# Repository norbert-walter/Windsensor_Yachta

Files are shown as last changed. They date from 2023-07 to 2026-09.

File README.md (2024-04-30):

## Windsensor Yachta

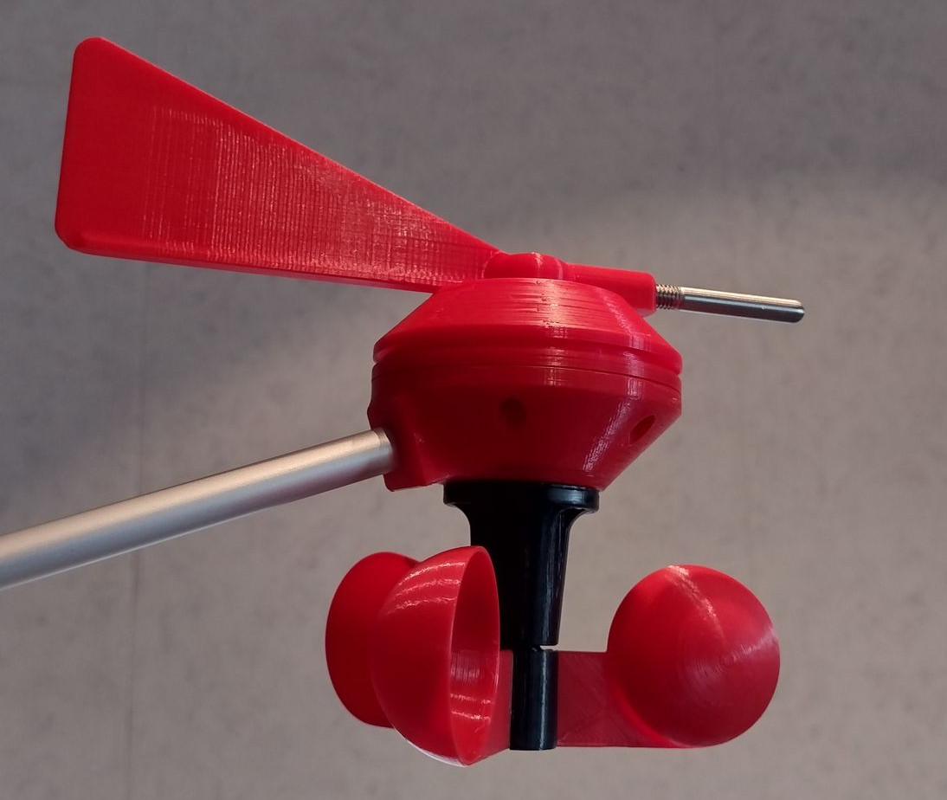
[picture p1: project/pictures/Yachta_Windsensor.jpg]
Windsnesor Yachta


Image: Wind Sensor Yachta

The initial idea for the Yachta wind sensor is based on a work by the user Yachta. He presented and published the wind sensor on [Thingiverse](https://www.thingiverse.com/thing:2261719). Udo took up the idea of Yachta and modified the mechanics a little. The arms of the cup wheel have been separated. This makes 3D printing easier to implement. The electronics were completely redesigned by him. The microcontroller was removed and replaced with an ESP8266. A DC/DC converter module was installed so that the wind sensor can also be operated at 12V. The circuit board was created with the Windows software Sprint Layout and converted into Gerber files. Now is a new BCP available from Norbert.

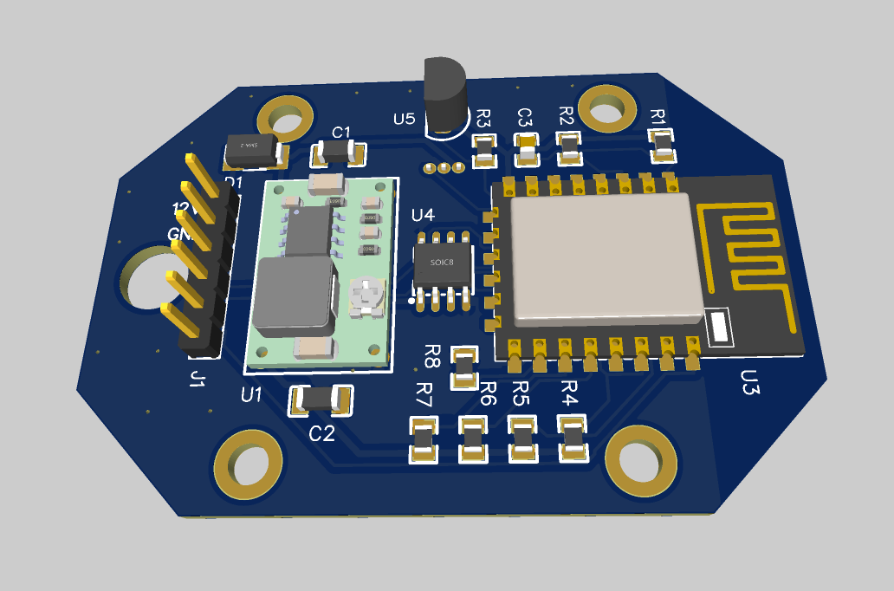
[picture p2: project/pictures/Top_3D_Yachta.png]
Windsnesor Yachta


Image: PCB board

The PCB project is listed on [Open Source Hardware Lab](https://oshwlab.com/) an can be edited with the webbased online [layout program EasyEDA](https://easyeda.com/norbert-walter/projects).

The board without components can be ordered from [Aisler](https://aisler.net/p/VTNPJWKQ) or direct in EasyEDA.

There are different firmware for the wind sensor. Both Udo and Julian ([Jukolein](https://github.com/jukolein/NMEA0183-Windsensor)) have created their own firmware versions with different functionality. Udo has also designed another wind sensor, which is a further development of the Yachta wind sensor. The functional principle and the electronics are identical. But you need a different board because the wind sensor is slimmer. Julian published the whole thing on [Github](https://github.com/jukolein/NMEA0183-Windsensor) and wrote his own firmware for the wind sensor, which can also be used for this wind sensor. 

The WiFi 1000 firmware is a firmware that can be used universally for various wind sensors and was originally developed by Norbert for the [WiFi 1000 wind sensor](https://gitlab.com/norbertwalter67/Windsensor_WiFi_1000). The current versions of the firmware can be found in the respective own repositories at Github and GitLab.

A lively exchange of experiences takes place in the German-speaking [sailing forum](https://www.segeln-forum.de/board194-boot-technik/board195-open-boat-projects-org/79131-windsensor-ii-iii/). You can also participate in English.

If you like to help or consider this project useful, please donate. Thanks for your support!

Donate (https://www.paypal.com/cgi-bin/webscr?cmd=_s-xclick&hosted_button_id=5QZJZBM252F2L)

## Technical characteristics

* Measuring wind speed and wind direction
* Robust mechanics
* Without special metal parts
* All parts can be found in the hardware store
* Easy 3D parts
* Weight app. 210g
* Weatherproof and UV stable
* No cabling for sensor signals
* Digital signal transmission with WiFi only
* 12V power supply utilizing top light power cable
* Using a ESP8266 for WiFi and data handling
* Update rate 1 samples per second
* No onboard instrument required
* Visualisation in OpenPlotter via laptop, mobile fone or tablett
* Web interface for operation
* No extra software required (display is the browser)
* Supporting  NMEA 0183 protocol
* Firmware update via Internet

## Create your own code

You have the option of creating your own code using the online [software development environment Gitpod](https://gitpod.io/#https://github.com/norbert-walter/Windsensor_Yachta). Follow this link and a finished development environment similar to PlatformIO will be created that runs in your browser with all code components. To compile the software, enter ***bash run*** in the terminal. In the workspace you will find the compiled binary code under ***.pio/build/d1_mini/firmware.bin***. With a right click you can download the binary file.

## Device flash process

With the [Web Flash Tool](https://norbert-walter.github.io/Windsensor_Yachta/flash_tool/esp_flash_tool.html) you can very easily flash the device with the firmware from the web browser. You need a Chrome or Edge browser and a USB connection cable. If the device is connected to the USB port of the computer, the serial connection can be selected and the flash process can then be started.

## Firmware characteristics

**Wind Sensor Yachta Firmware**
* Web configuration and graphical visualisation
* Webserver port 80
* TCP port 6666
* TCP NMEA0183 telegram MWV, VWR, VPW, INF
* JSON http://192.168.4.1/json
* Firmware update via Internet
* Android App

## How can I use it?

I use the windsensor in combination with [OpenPlotter](http://www.sailoog.com/openplotter) on a Raspberry Pi 3B. OpenPlotter serves as access point for WiFi devices. The windsensor connects to OpenPlotter via WiFi and transmits the NMEA0183 data telegrams every second. The windsensor sends NMEA0183 telegrams. Check here [link](http://www.nmea.de/nmea0183datensaetze.html) for more information. 

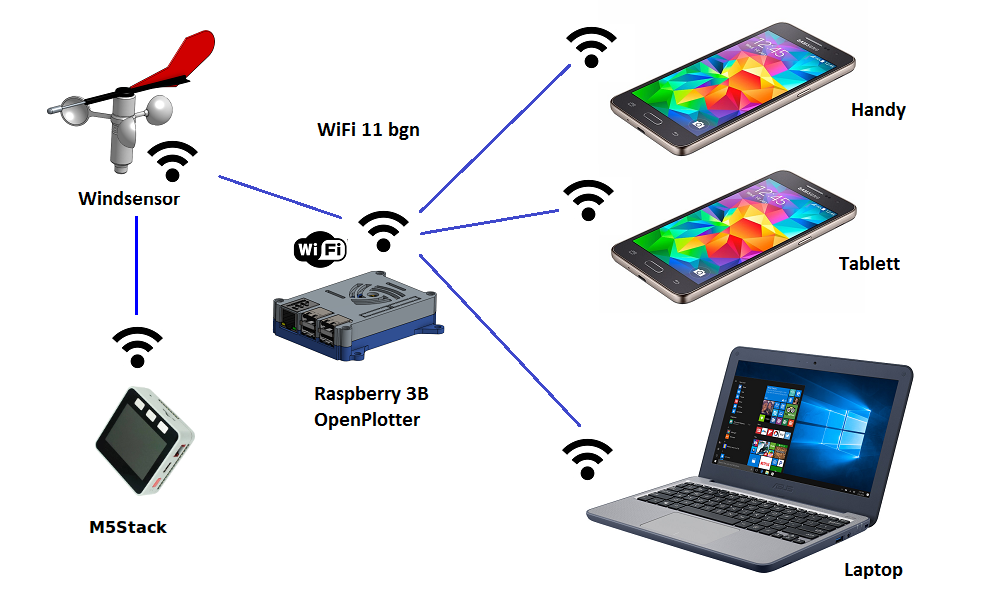
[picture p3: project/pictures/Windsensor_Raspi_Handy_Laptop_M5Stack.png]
Connectivity


Img: Connection options

Now also available as Android App. It is is a WebApp connecting directly to the windsensor to display all data.

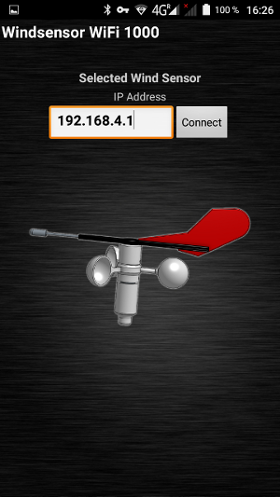
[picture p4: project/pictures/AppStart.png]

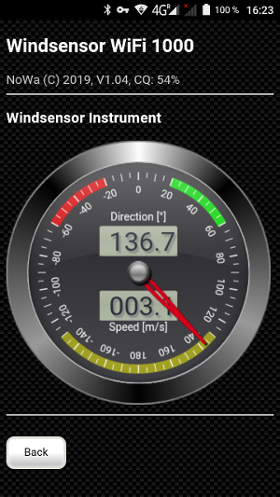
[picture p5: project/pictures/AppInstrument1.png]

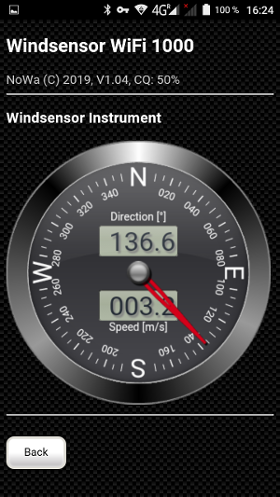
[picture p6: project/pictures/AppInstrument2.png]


Img: Android App for Wifi 1000 firmware

## What is the current status?

I have completed many tasks but still not everything is perfect so far.

- [x] Technical recherche
- [x] Evaluation of function
    - [x] Hall sensors and rotation sensor
    - [x] Magnets
    - [x] Prototype circuit
    - [x] Test software
    - [x] Web display technologies
    - [x] 3D material test
    - [x] Coating tests
- [x] Mechanical design
    - [x] 3D parts
- [x] Electronic design
    - [x] Circuit design
    - [x] Board design
    - [x] Customer sample circuit
- [ ] Software
    - [x] Basic functionality
    - [x] NMEA0183 WiFi
    - [x] NMEA0183 Serial
    - [x] mDNS Service
    - [x] JSON
    - [ ] MQTT
    - [ ] Wind History Diagram
    - [x] Sensor Data Diagram for diagnostic and mechanical adjustment
    - [x] Web-Updater
    - [x] Web-Configurator
    - [x] Web server as data display
    - [x] Andoid App
    - [x] External Diagnostic Tool
	- [x] Support for other wind sensor types
- [x] Components ordering
    - [x] Electronic board
    - [x] Mechanical parts
    - [x] Fittings
- [x] Prototyp creation
    - [x] Yachta prototype
    - [x] Modifyed Yachta prototype
- [x] Production Zero series
    - [x] DIY Kits
    - [x] Assembled windsensor
- [x] Shipping Zero Series
- [x] Documentation
    - [x] Technical description
	- [x] Description Web frontend
    - [x] Construction manual
    - [x] Part list
    - [x] User manual
    - [x] Data sheet
- [ ] Application tests
    - [x] Temperature 20...80°C
    - [x] Vibration test by strong wind (8bft)
    - [x] WiFi stability test
    - [x] Connection test
    - [x] Rain test
    - [ ] IPX6 Water resistance test
    - [x] UV radiation test
    - [x] Long time test
    - [x] Test with auto pilot
    - [x] User experiences
- [ ] Extensions
    - [x] Multi function display with M5Stack
    - [ ] NMEA2000 Gateway
    - [x] Weather data sensor with BME280
- [ ] Certification
    - [ ] CE Certification

## Questions?

For questions or suggestions please get in contact via email at norbert-walter(at)web.de.

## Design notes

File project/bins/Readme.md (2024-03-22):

**20240322 firmware_V1.20.wsb `(stable)`**

* Change the network address from 192.168.4.1 to 192.168.5.1
* This solv connection problems with other ESP32 and ESP8266 hardware that used the standard IP address 192.168.4.1
* In most cases, this change has no impact on existing configurations. In external software you must change the IP address.
* Add a link to changelog on page Update
* WLAN default settings (SSID: Yachta, Pass: 12345678, IP: 192.168.5.1)

**20240320 firmware_V1.19.wsb `(old)`**

* Reorganisation server mode NMEA Serial
* Supports Clipper Wind daughter display via NMEA0183 
* Details: https://www.segeln-forum.de/thread/67401-windsensor-diy/?postID=2623770#post2623770
* WLAN default settings (SSID: Yachta, Pass: 12345678, IP: 192.168.4.1)

**20230724 firmware_V1.18.wsb `(old)`**

* Repository changed from GitLab to GitHub
* Gitpod integration
* Temperature compensation for DS18B20
* Supports wind sensor PCB Yachta 2.0 with new magnetic rotation sensor MT6701 
* WLAN default settings (SSID: Yachta, Pass: 12345678, IP: 192.168.4.1)

`Attention! After update changes all settings to default values. Please renew the settings.`

**20220906 firmware_V1.17.wsb `(old)`**

* Fix for calibration
* WLAN default settings (SSID: NoWa, Pass: 12345678, IP: 192.168.4.1)

**20220901 firmware_V1.16.wsb `(old)`**

* Fix for negativ wind speed when using calibration
* Fix libs for compiling  with arduino IDE 1.8.19
* Modification for longer passwords with special character
* WLAN default settings (SSID: NoWa, Pass: 12345678, IP: 192.168.4.1)

**20220520 firmware_V1.15.wsb `(old)`**

* Fix for wind direction offset (hanging values)
* Fix for calibration (eliminates negativ values to zero)
* WLAN default settings (SSID: NoWa, Pass: 12345678, IP: 192.168.4.1)

**20210910 firmware_V1.14.wsb `(old)`**

* Support for new PCB for wind sensor Yachta
* 1Wire pin canged from GPIO15 to GPIO12 (new PCB)
* WLAN default settings (SSID: NoWa, Pass: 12345678, IP: 192.168.4.1)

`Attention! No support for old PCB from Udo for wind sensor Yachta.`

**20210827 firmware_V1.13.wsb `(old)`**

* Support for modifyed wind sensor Ventus W132
* New values for device informations page
* New values for Wind Values page
* Support BME280 and DS18B20
* New NMEA0183 custom telegram WSE for BME280
* Solved problem for TCP telegram transmission (remove CR for unselected telegrams)
* WLAN default settings (SSID: NoWa, Pass: 12345678, IP: 192.168.4.1)

**20210819 firmware_V1.12.wsb `(old)`**

* Secure function for autopilot (limit and reduce jumping measured values)
* WLAN default settings (SSID: NoWa, Pass: 12345678, IP: 192.168.4.1)

**20210811 firmware_V1.11.wsb `(old)`**

* Fix for hanging I2C bus if the AS5600 is not present by WiFi1000 wind sensor
* Limit jumping direction values by using AS5600
* Rename the wind sensor types and add two new sensors:
	old: (NOWA1000|Udo1|Udo2)
	new: (WiFi1000|Yachta|Jukolein|Davis|Ventus)
* Using different speed calculations for different wind sensor types (radius)
* Using pictograms for wind values
* WLAN default settings (SSID: NoWa, Pass: 12345678, IP: 192.168.4.1)
* `Needs new Android App!`

`Attention! After update changes all settings to default values. Please renew the settings.`

**20210805 firmware_V1.10.wsb `(critical)`**

* Add two new wind sensor types ([Yachta](https://www.thingiverse.com/thing:2261719) and [Jukolein](https://github.com/jukolein/NMEA0183-Windsensor))
* WLAN default settings (SSID: NoWa, Pass: 12345678, IP: 192.168.4.1)

**20210501 firmware_V1.09.wsb `(old)`**

* CPU speed changed from 80 MHz to 160 MHz for more performance
* nDNS service added for NMEA0183 ZeroConfig with AVnav
* Hostmane support fixed
* WLAN default settings (SSID: NoWa, Pass: 12345678, IP: 192.168.4.1)

`Attention! After update changes all settings to default values. Please renew the settings.`

**20210325 firmware_V1.08.wsb `(old)`**

* Downwind values now correct
* Diagnostic Mode fixed
* Average building fixed

**20200711 firmware_V1.07.wsb `(old)`**

* Boot problem fixed by wind speed higher 4bft (Boot Loop)
* Elektronic tested until 180km/h wind speed with sysntetic signals
* Direction accuracy 10x improved. Now is accuracy by 1° for 12bft or 78kn wind speed
* Display problem fixed for negativ wind direction in Canvas Steel instrument
* New parameter added for WiFi channel setting (1...13)
* WiFi connections reduced from 4 to 2 clients for better performance 
* WLAN default settings (SSID: NoWa, Pass: 12345678, IP: 192.168.4.1)

`Attention! After update changes all settings to default values. Please renew the settings.`

**20200427 firmware_V1.06.wsb `(old)`**

* Firmware update changed (GitLab download now available)
* For SSID special characters added (A..z, 0..9, _-)
* WLAN indicator for connection quality fixed
* WLAN default settings (SSID: NoWa, Pass: 12345678, IP: 192.168.4.1)

`Attention! After update changes all settings to default values. Please renew the settings.`

**20190928 firmware_V1.05.wsb `(old)`**

* Using the actual Espressif SDK 2.2.1(cfd48f3)
* Restart now available via Web configuration
* Firmware update changed (GitLab download has been removed)
* New feature! Added a new calibration function for wind speed
* New feature! Added password for configuration pages (default: 12345678)
* WLAN default settings (SSID: NoWa, Pass: 12345678, IP: 192.168.4.1)
* Diagnostic Mode fixed (No connection and answare from wind sensor by using newer web browser)

`Attention! After update changes all settings to default values. Please renew the settings.`

**20190428 firmware_V1.04.wsb `(old)`**

* Reset start values for speed and direction after reboot (eleminate start spikes)
* Link problem in HTML error page 404 solved
* JSON string for ServerMode fixed (before string, after int)
* New feature! Oscilloscope function included
* New JSON device created for oscilloscope data sending
* Diagnostic Mode activated (starts the oscilloscope function, usable with external Diagnostic Tool)
* Pulse Counter added in Device Info page (count the pulse per revolution for the direction Hall sensor)
* New complex instrument added when true wind selected (instrument with full degree scale and cardinal points, without sections, useful for Weather Station Mode)

**20190424 firmware_V1.03.wsb `(old)`**

* Fixing the wind speed problem by slow winds
* Fixing the wind speed problem for bft unit (uncorrect calculation)
* Fixing the wind speed problem for m/s and km/h in Demo Mode (missing values)
* Fixing WLAN connection quality for Demo Mode (if no connection then uncorrect values )
* Adding in Web configuration a new parameter "Connection Timeout" (solved the start problem with OpenPlotter)
* Styling changed in page "Settings"

`Attention! After update changes all settings to default values. Please renew the settings.`

**20190220 firmware_V1.02.wsb `(old)`**

* Blinking text in demo mode fixed (red syle)
* Individual help text depends on firmware version

**20190220 firmware_V1.01.wsb `(old)`**

* Problem with average setting solved (now updating directly)
* Average value 10 now usable
* Info message in Demo Mode for Instrument page and Device Info page
* Offset for wind direction inserted (new feature)
* Two step update not more necessary
* Any english messages changed

**20190217 firmware_V1.00.wsb `(old)`**

* First actual firmware V1.00
* Critical WLAN settings solved (now checking all input values)
* Implement online update function via GitLab
* SSID: MyBoat
* Pass: S6587rr94P

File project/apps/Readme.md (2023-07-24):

**20210811 Windsensor_WiFi_1000_6.apk `(stable)`**

* Necessary for firmware V1.11 (different device name)

**20190205 Windsensor_WiFi_1000_5.apk `(stable)`**

* If the App running then disable the display timeout

**20190205 Windsensor_WiFi_1000_4.apk `(old)`**

* Checking the type of connection (is this a wind sensor)
* Reading the device type from JSON
* Open the following page only if detect a wind sensor
* Error handling by incorrect connections (messaging)

**20190205 Windsensor_WiFi_1000_3.apk `(old)`**

* Added a settings page with IP selection
* Saving the last IP in a data base
* No error handling implemented

**20190205 Windsensor_WiFi_1000.apk `(old)`**

* First App version with fix connection to norbert-walter.dnshome.de
* Usable only for Demo Software
* No error handling implemented

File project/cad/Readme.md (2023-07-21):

## Information

The PCB board without components can be ordered from [Aisler](https://aisler.net/p/VTNPJWKQ).

If you need eany changes on the PCB then you can use EasyEDA. The project is located on [Open Source Hradware Lab (OSHWLab)](https://easyeda.com/norbert-walter/projects).

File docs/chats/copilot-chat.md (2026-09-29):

# Copilot-Chat: Python-Umgebung und Chat-Sicherung

## Python und `run`

Das Shell-Skript `run` installiert `esptool` und PlatformIO mit `pip3` und kompiliert anschließend die Firmware. Auf dem verwendeten Debian-13-System fehlten zunächst `python3` und damit auch `pip3`.

Nach Installation von Python, pip und venv lässt sich eine virtuelle Umgebung im Projekt mit folgendem Befehl erstellen:

```bash
python3 -m venv .venv
```

Das ist normalerweise einmal nötig, solange der Ordner `.venv` erhalten bleibt. Nach einem neuen Terminal muss die Umgebung aktiviert werden:

```bash
source .venv/bin/activate
```

Wird der Workspace neu erstellt und `.venv` dabei gelöscht, muss sie neu angelegt werden.

## Copilot-Chat sichern

Copilot-Chats werden nicht automatisch im Projektordner gespeichert. Für eine dauerhafte Projektnotiz können wichtige Nachrichten oder Zusammenfassungen als Markdown im Projekt abgelegt werden. Diese Datei liegt unter `docs/chats/copilot-chat.md`.

Vor dem Commit prüfen, dass keine vertraulichen Informationen wie Tokens oder Passwörter enthalten sind.

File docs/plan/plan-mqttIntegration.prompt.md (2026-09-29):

## Plan: MQTT-Telemetrie integrieren

MQTT im vorhandenen Server-Modus `2` als exklusiven Telemetrie-Ausgang ergänzen. Brokerdaten werden über die Web-Einstellungen verwaltet; Messwerte gehen in einem kompakten JSON-Payload an ein sensorindividuelles Topic. Verbindungsaufbau und Publish müssen nicht-blockierend bleiben, damit Messwerterfassung, HTTP-Konfiguration und MQTT-Keepalive weiterlaufen.

**Schritte**
1. MQTT-Client-Bibliothek für ESP8266 (voraussichtlich PubSubClient) als PlatformIO-Abhängigkeit aufnehmen und Broker-Client mit `WiFiClient` anlegen.
2. Brokerkonfiguration ergänzen: Host, Port, optionaler Benutzername und Passwort als Felder in `configData`; EEPROM-Strukturversion erhöhen und beim Booten bestehende Konfigurationen migrieren, statt sämtliche Nutzereinstellungen durch neue Defaults zu ersetzen. `settings_html.h` und `Settings()` um Eingabe und Validierung ergänzen.
3. Zugangsdaten nicht über die bestehende GET-Übergabe von `/settings` senden: Formular/Handler für diese Speicherung auf POST umstellen oder GET für übrige Einstellungen beibehalten und Broker-Zugangsdaten separat per POST übernehmen. Passwort nicht unnötig im Formular als Klartext vorbelegen. Hinweis: HTTP und EEPROM bleiben ohne zusätzliche Maßnahmen unverschlüsselt.
4. `WiFi_Windsensor.cpp`: Brokerparameter setzen, Verbindung nach vorhandener WLAN-Verbindung herstellen und Reconnect mit `millis()`-Backoff statt blockierender Dauerschleife ausführen. MQTT-Protokollpflege muss im äußeren `loop()` und auch in der bestehenden wartenden TCP-Client-Schleife stattfinden; andernfalls kann `mqttClient.loop()` verhungern.
5. Bei `serverMode == 2` nur MQTT publizieren. Kleines JSON-Payload für Windrichtung/-geschwindigkeit und konfigurierte optionale Temperatur-/Umweltdaten auf ein eindeutiges Topic wie `windsensor/<sensorID>/telemetry`; dafür stabile Snapshot-Werte aus den globalen Messgrößen verwenden und die MQTT-Paketgrößenbegrenzung berücksichtigen. Publish-Takt zunächst an den vorhandenen normalen/reduzierten Sendetakten ausrichten.
6. Verbindungsstatus und Fehler knapp über vorhandenes Debug-Logging ausgeben; bei nicht verfügbarem Broker Sensorberechnung, Webserver und andere Betriebsmodi unbeeinträchtigt lassen.

**Relevante Dateien**
- `/home/coder/Windsensor_Yachta/platformio.ini` — MQTT-Bibliothek hinzufügen.
- `/home/coder/Windsensor_Yachta/src/WiFi_Windsensor.cpp` — Clientinitialisierung, Reconnect, Loop-Service und Publish im Modus 2.
- `/home/coder/Windsensor_Yachta/src/Configuration.h` — persistente Brokerfelder und Konfigurationsversionsnummer.
- `/home/coder/Windsensor_Yachta/src/FunctionsLib.h` — EEPROM-Laden/Speichern; vorhandene Implementierung liest/schreibt das gesamte Struct.
- `/home/coder/Windsensor_Yachta/src/settings_html.h` — Broker-Eingaben und Update der Settings.
- `/home/coder/Windsensor_Yachta/src/ServerPages.h` — HTTP-Methode/Handler für sichere Übermittlung der Brokerdaten.
- `/home/coder/Windsensor_Yachta/src/Definitions.h` — aktuelle globale Messwerte und Sendetimer/Flags als Quelle für das Payload und Publishintervall.

**Verifikation**
1. PlatformIO-Build für `d1_mini` ausführen.
2. Mit MQTT-Broker testen: Verbindung/Authentifizierung, Topic und JSON-Payload, aktiver und ruhender Wind, optionale Sensorwerte sowie `serverMode == 2`.
3. Broker-Ausfall/Neustart testen: Firmware bleibt responsiv, reconnectet begrenzt und MQTT-Keepalive bleibt bei einem verbundenen TCP-Client aktiv.
4. Bestehende EEPROM-Konfiguration mit neuer Firmware laden und sicherstellen, dass alte WLAN-/Sensor-Einstellungen erhalten bleiben; danach Brokerdaten speichern und Neustartpersistenz prüfen.
5. Modus 0, 1, 3 und 4 smoke-testen, um unveränderte HTTP/NMEA-, Diagnose- und Demo-Funktionen sicherzustellen.

**Entscheidungen**
- Vom Nutzer gewählt: Brokerkonfiguration in der Web-Einstellungsseite; gemeinsames JSON-Paket; MQTT exklusiv in Server-Modus 2.
- Angenommen: ausgehende Telemetrie ohne MQTT-Subscriptions oder Remote-Steuerung; QoS 0 genügt zunächst; Topic enthält die `sensorID`.
- Sicherheit: Broker-Passwort darf nicht in GET-URLs erscheinen. HTTP/EEPROM-Verschlüsselung und TLS zum Broker sind nicht im Basisumfang und müssen bei Anforderungen an Schutz außerhalb des lokalen Netzes separat festgelegt werden.

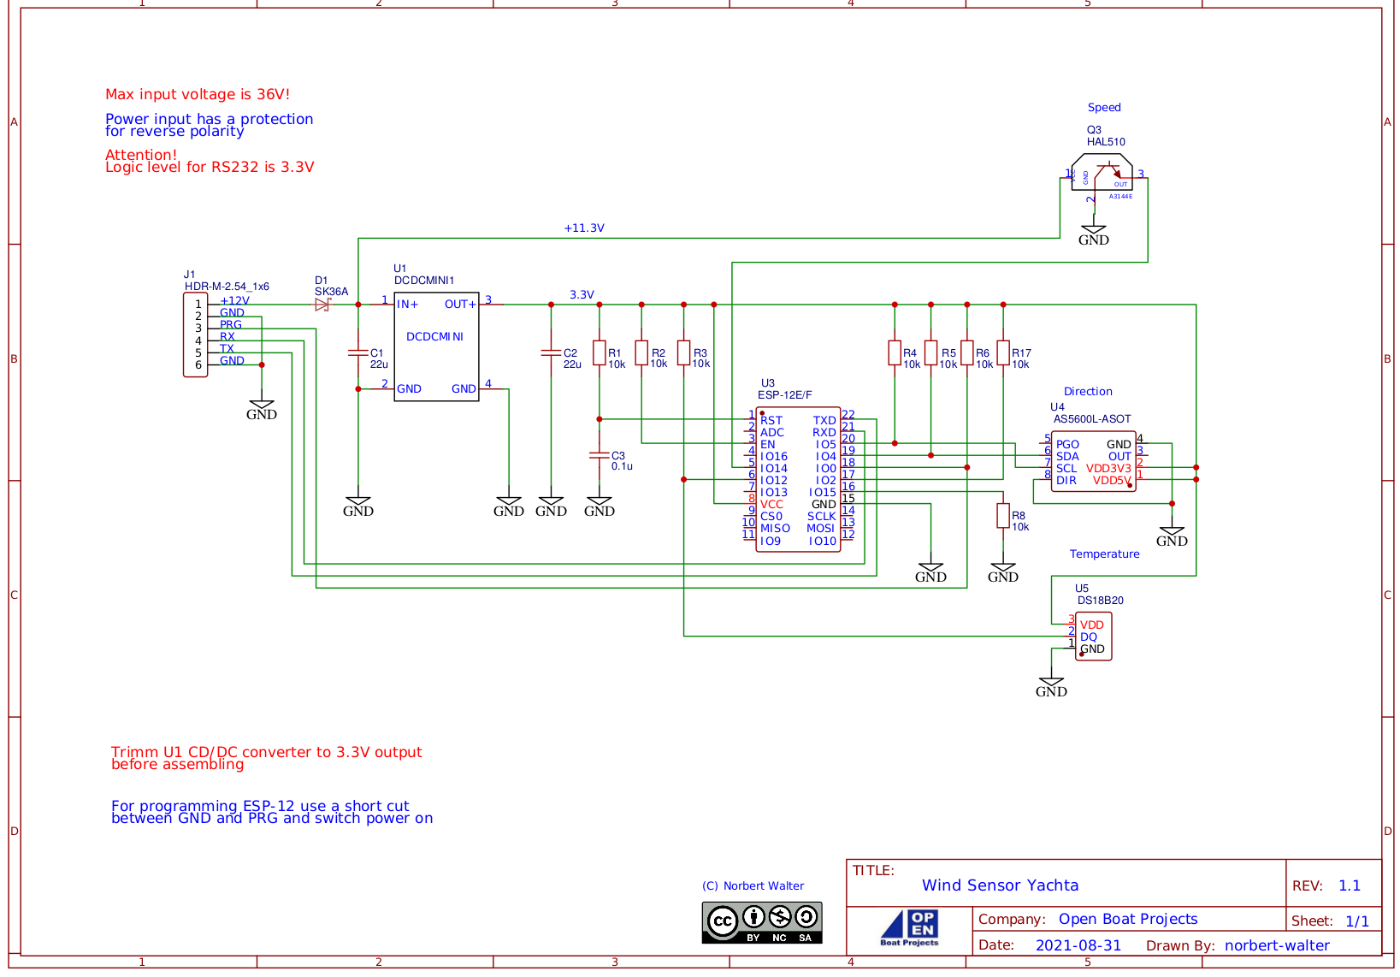
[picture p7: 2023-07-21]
project/cad/Schematic/Schematic_Yachta.png

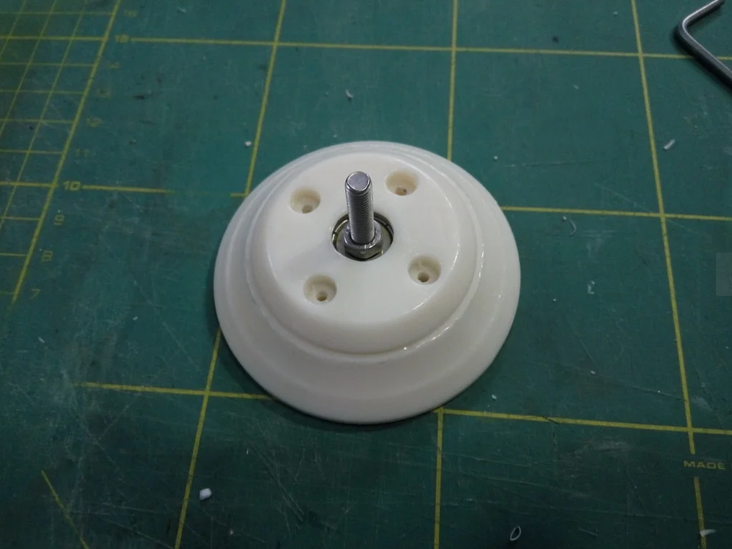
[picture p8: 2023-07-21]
project/pictures/Yachta_Thingiverse/Yachta4.png

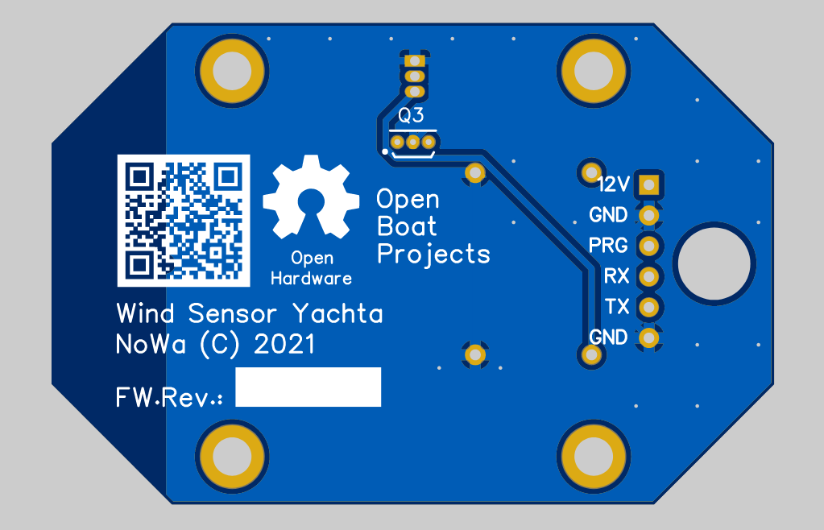
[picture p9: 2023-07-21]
project/pictures/Bottom_Yachta.png

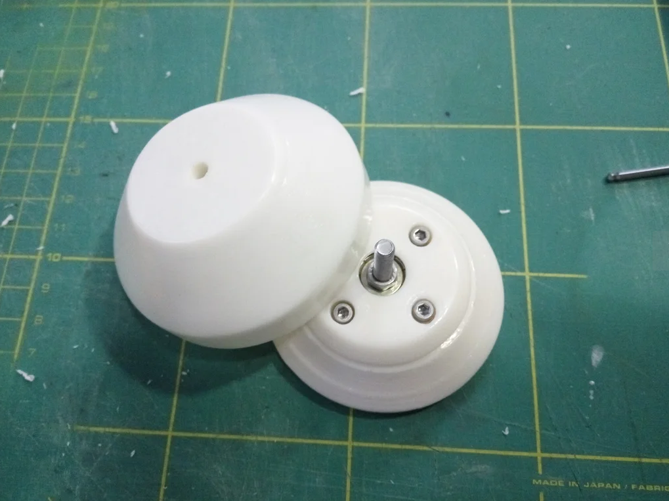
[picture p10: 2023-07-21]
project/pictures/Yachta_Thingiverse/Yachta6.png

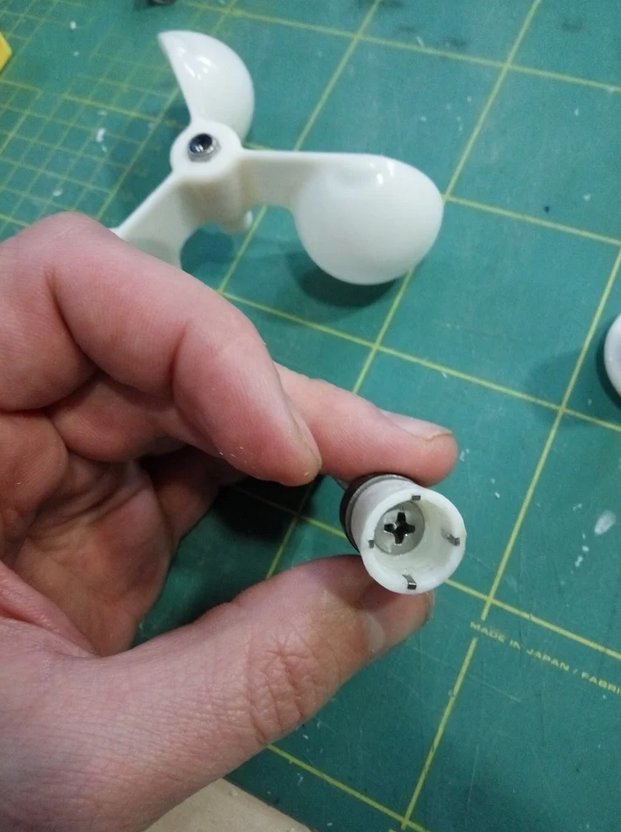
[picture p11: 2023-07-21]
project/pictures/Yachta_Thingiverse/Yachta12.png

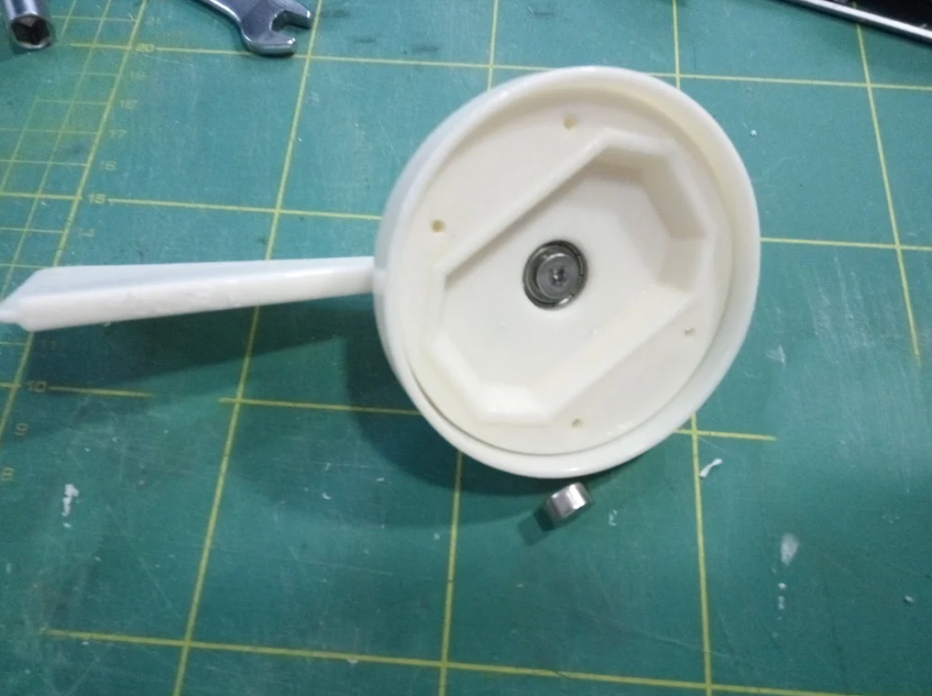
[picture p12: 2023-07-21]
project/pictures/Yachta_Thingiverse/Yachta9.png

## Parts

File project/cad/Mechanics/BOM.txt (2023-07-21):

Material:
#########

15x wood screw 3x10 or Allen scew M3x10
1x Allen screw M5 x 60 with smooth shaft 35 mm 
1x Cross recess  screw M5 x 60
1x countersunk screw M5 x 25
2x stop nut M5
1x nut M5
2x ball bearings 16x5x5 (625)
1x ball bearing 13x5x4 (695) or ceramic for the bottom
3x washer M5
4x neodymium magnets 1x1.5x5
1x neodymium magnet square 5x5x5

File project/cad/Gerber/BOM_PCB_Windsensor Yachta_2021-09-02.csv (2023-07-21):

ID | Name | Designator | Footprint | Quantity | Manufacturer Part | Manufacturer | Supplier | Supplier Part | Price
1 | SS40AF | Q3 | A3144E_HALLSENSOR_COPY | 1 | SS40AF | Honeywell | LCSC | C778657 | 0.27
2 | ES2DA | D1 | DO-214AC | 1 | ES2DA | Yangzhou Yangjie Elec Tech | LCSC | C698723 | 0.045
4 | 10k | R7,R6,R8,R4,R5 | R0805 | 5 | 0805W8F1002T5E | Uniroyal Elec | LCSC | C38522 | 0.002
6 | 10k | R3,R1,R2 | R0805 | 3 | 0805W8F1002T5E | Uniroyal Elec | LCSC | C38522 | 0.002
7 | DS18B20 | U5 | TO-92-3_L4.9-W3.7-P1.27-L | 1 | DS18B20 | Youtai Semiconductor Co., Ltd. | LCSC | C376006 | 0.787
9 | ESP-12E/F | U3 | WIFIM-SMD_ESP-12E | 1 | ESP-12E | Ai-Thinker | LCSC | C89297 | 2.446
10 | 22u | C2,C1 | C1206 | 2 | CL31A226KAHNNNE | SAMSUNG | LCSC | C12891 | 0.067
11 | 0.1u | C3 | C0805 | 1 | C0805X104K101TB | IHHEC(HOLY STONE ENTERPRISE CO., LTD) | LCSC | C495959 | 0.017
12 | AS5600L-ASOT | U4 | SOIC-8_L5.0-W4.0-P1.27-LS6.0-BL | 1 | AS5600L-ASOT | 美国AMS | LCSC | C499458 | 1.361

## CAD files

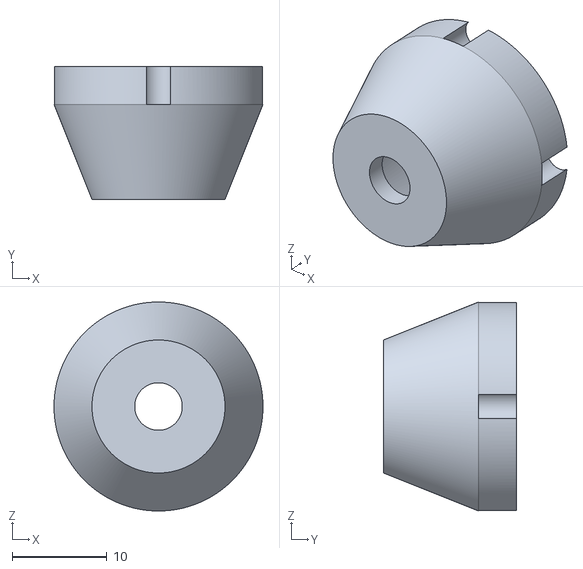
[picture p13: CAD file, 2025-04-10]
project/cad/3D-Parts/magnet_holder_2.stl
22.0 x 14.0 x 22.0

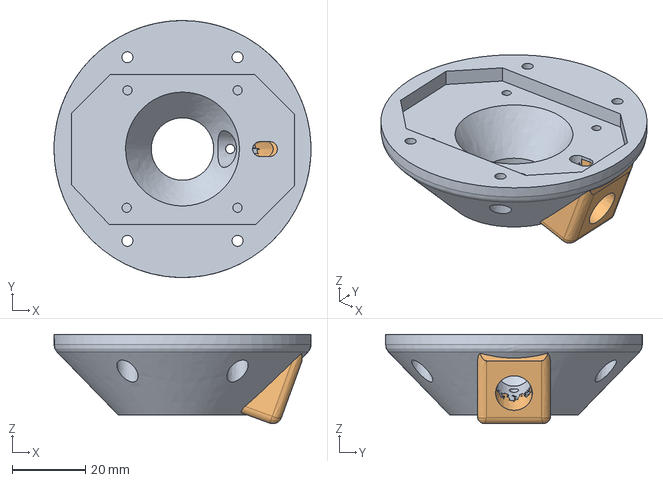
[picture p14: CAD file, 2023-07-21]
project/cad/Mechanics/IGES/Unterteil.iges
70.0 x 70.0 x 24.4 mm

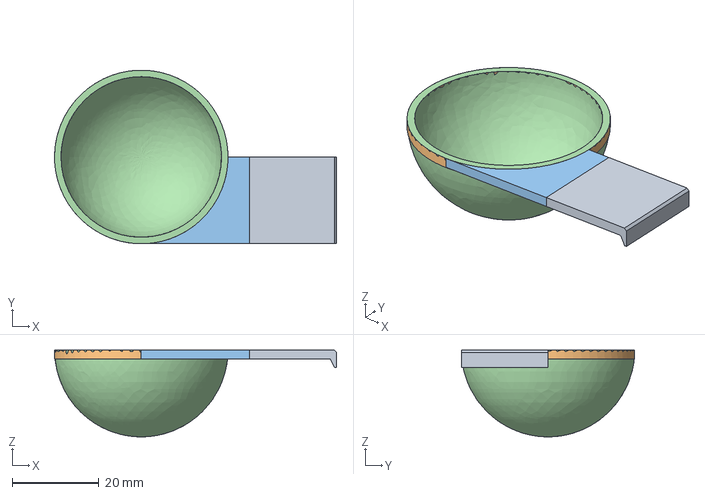
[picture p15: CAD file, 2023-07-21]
project/cad/Mechanics/IGES/Loeffel_rund.iges
65.0 x 40.0 x 20.0 mm

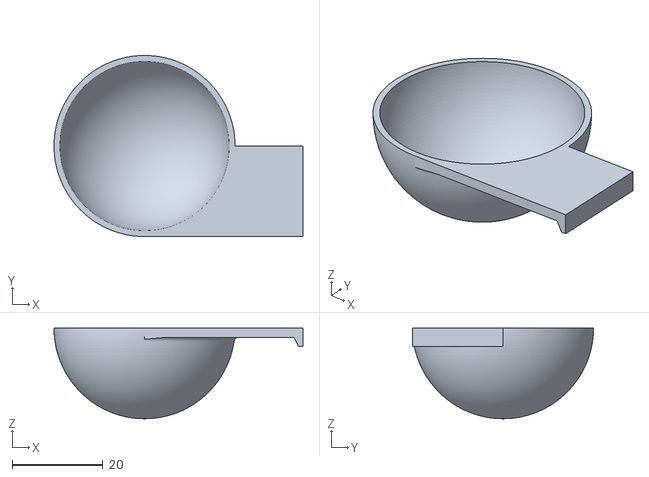
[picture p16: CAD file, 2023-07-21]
project/cad/3D-Parts/cup_round.stl
55.0 x 40.0 x 20.0

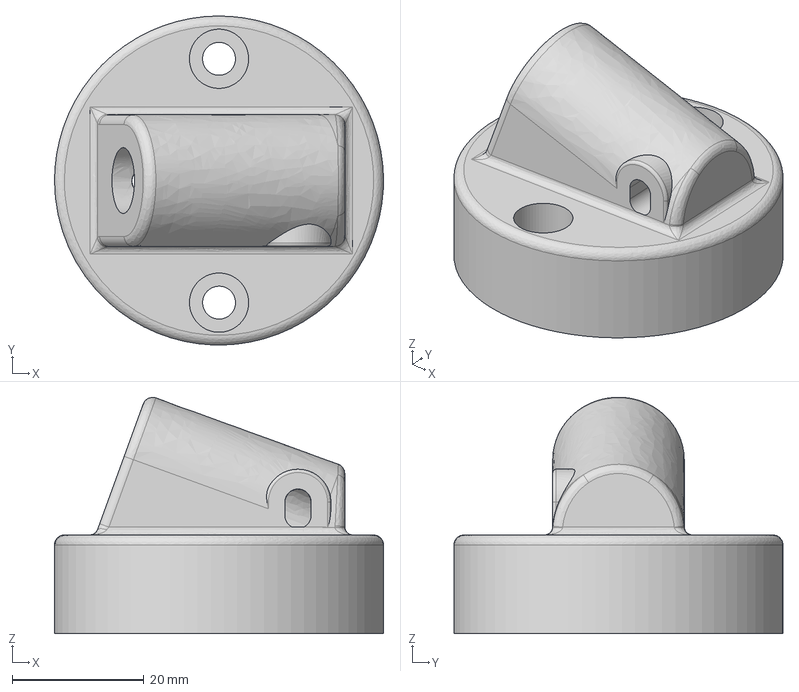
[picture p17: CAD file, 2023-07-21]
project/cad/Mechanics/IGES/Fuss_regler.iges
50.0 x 50.0 x 35.9 mm

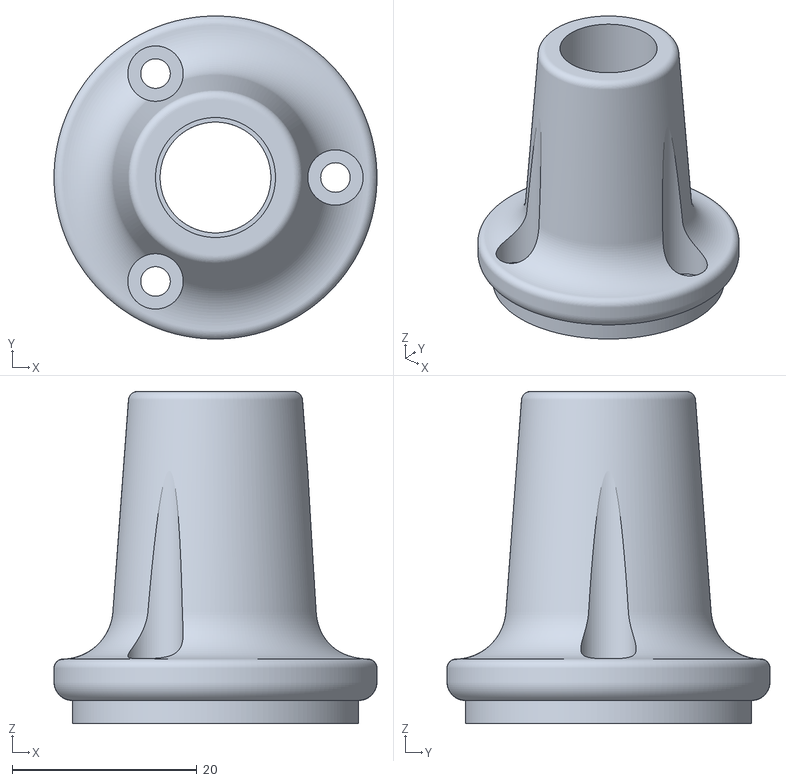
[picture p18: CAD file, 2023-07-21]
project/cad/3D-Parts/bot_ball_bearing.stl
35.0 x 35.0 x 36.0

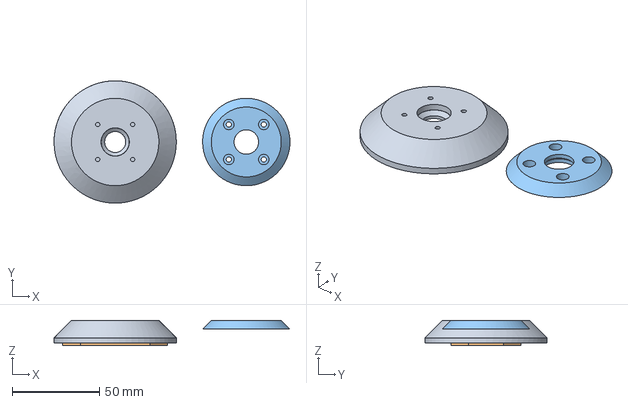
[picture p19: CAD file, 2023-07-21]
project/cad/Mechanics/IGES/Oberteil.iges
135.0 x 70.0 x 14.5 mm

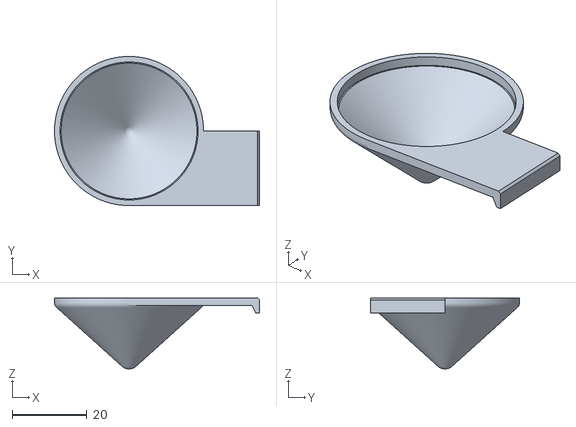
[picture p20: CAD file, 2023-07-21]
project/cad/3D-Parts/cup_pointed.stl
55.0 x 40.0 x 19.0

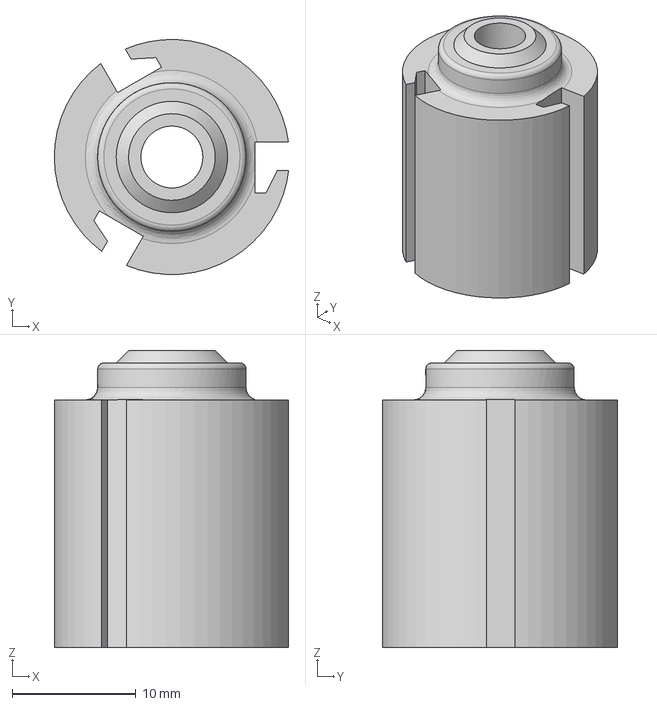
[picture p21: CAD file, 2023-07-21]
project/cad/Mechanics/IGES/Loeffel_mitte.iges
18.9 x 19.0 x 24.0 mm

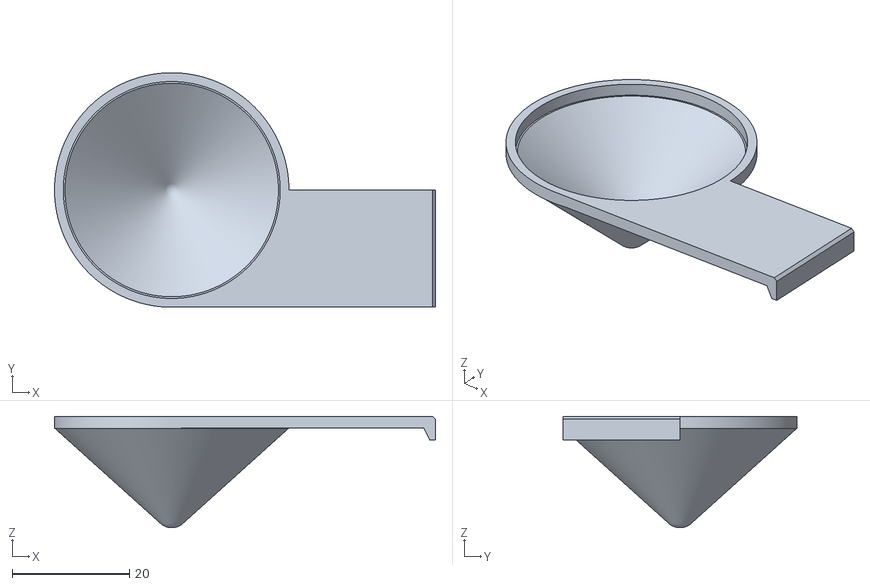
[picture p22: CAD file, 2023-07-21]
project/cad/3D-Parts/cup_pointed_long.stl
65.0 x 40.0 x 19.0

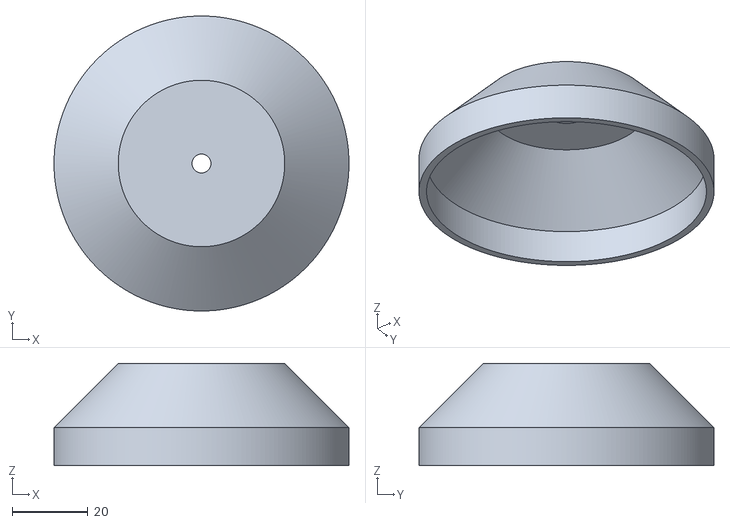
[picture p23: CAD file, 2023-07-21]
project/cad/3D-Parts/fane_support_big.stl
78.0 x 78.0 x 27.0

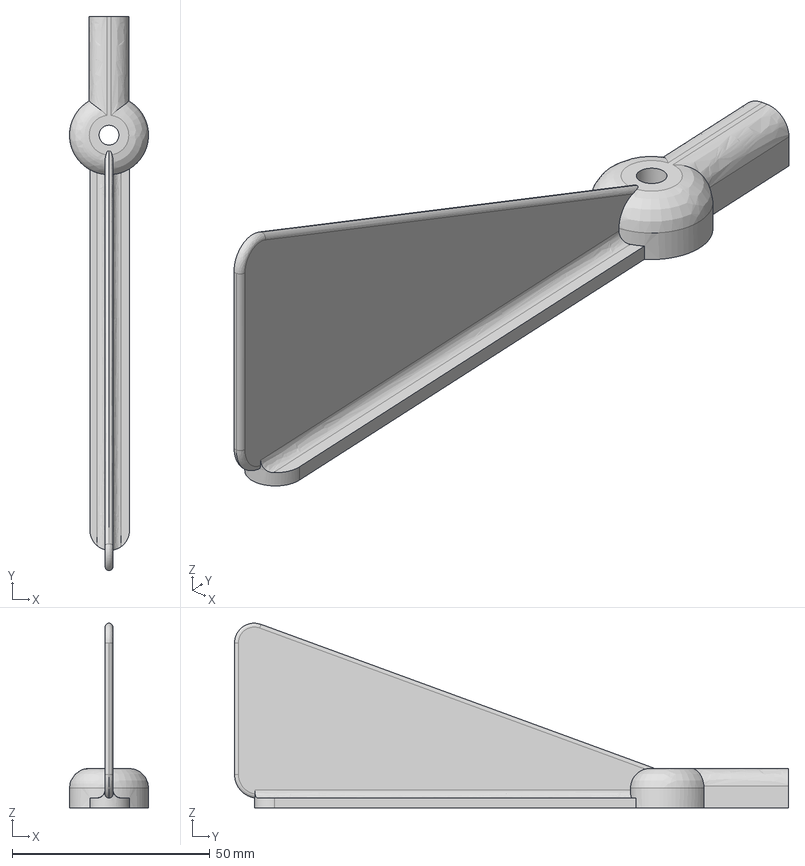
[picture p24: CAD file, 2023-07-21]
project/cad/Mechanics/IGES/Windfahne.iges
20.0 x 140.1 x 46.7 mm

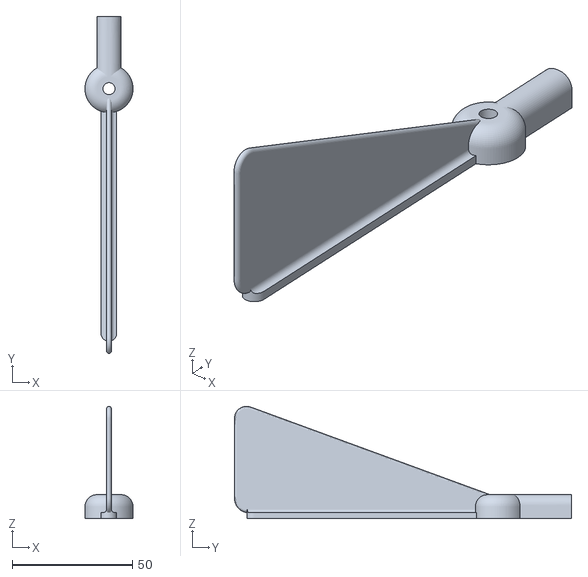
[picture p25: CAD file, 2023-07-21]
project/cad/3D-Parts/fane.stl
20.0 x 140.1 x 46.7

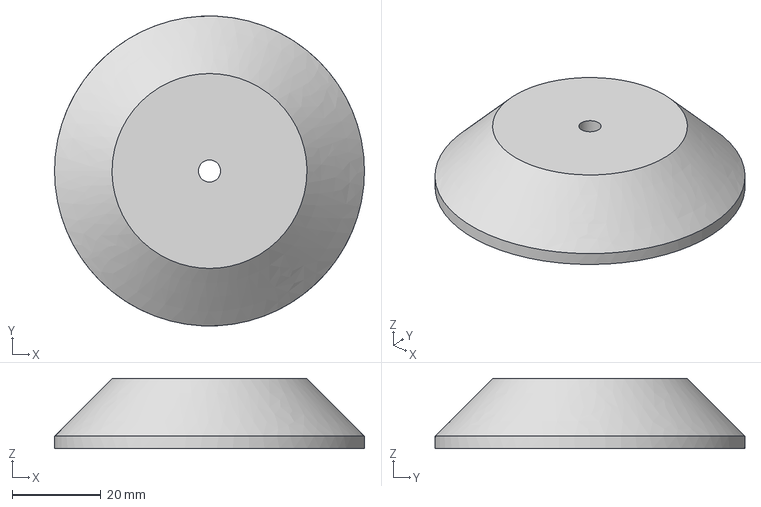
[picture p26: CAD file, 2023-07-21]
project/cad/Mechanics/IGES/Windex-Base.iges
70.0 x 69.9 x 15.8 mm

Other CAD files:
project/cad/3D-Parts/bot.stl
project/cad/Mechanics/IGES/Unterteil-2.iges
project/cad/3D-Parts/base_power.stl
project/cad/Mechanics/IGES/Loeffel_spitz v1.iges
project/cad/3D-Parts/base_cup_wheel.stl
project/cad/3D-Parts/fane_support_smal.stl
project/cad/3D-Parts/magnetholder.stl
project/cad/3D-Parts/top_1.stl
project/cad/3D-Parts/top_2.stl
project/cad/Mechanics/Fusion360/Loeffel-mitte.f3d
project/cad/Mechanics/Fusion360/Oberteil.f3d
project/cad/Mechanics/Fusion360/Unterteil-2.f3d
project/cad/Mechanics/Fusion360/Unterteil.f3d
project/cad/Mechanics/Fusion360/Windex-Base.f3d
project/cad/Mechanics/Fusion360/Windfahne.f3d
project/cad/Mechanics/Fusion360/base_power.f3d
project/cad/Mechanics/Fusion360/cup_pointed.f3d
project/cad/Mechanics/Fusion360/cup_round.f3d
project/cad/Mechanics/IGES/Magnethalter.iges

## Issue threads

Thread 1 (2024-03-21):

UDP ?

dagnall53, 2024-03-21:
I am trying to assist a user of your wifi Anemometer to connect into a boat network using a NMEA4WIFI multiplexer.
He will connect to the Multiplexer AP, (and will also connect a PC/Tablet (+openCPN) to this AP.)

It is not appropriate in this situation to use TCP for the anemometer<>multiplexer link, as the Multiplexer can only support a single TCP link, thus preventing the PC<>multiplexer from using TCP.

A better approach is to use UDP (broadcast) from the anemometer, as this data can then be "seen" both by the multiplexer and also by the Tablet/Pc that is also connected to the Multiplexer AP.

Open CPN has the facility to accept multiple  "connections" and I have confirmed with practical simulations that an Anemometer could (eg) send nmea0183 on UDP port 8080, and the Multiplexer can send (eg AIS etc) on UDP port 2000.

However, looking at the source code, I could not see any UDP transmission.  Is this hidden? or missing?
If Missing, is there a version of the software that offers UDP transmission options?

norbert-walter, 2024-03-21:
Hello,

   Thank you for your interest in the Yachta wind sensor. The firmware only supports a TCP connection. The Windsnesor is the TCP server and a client can connect to the server. UDP is not supported because it clutters up the network. UDP is usually transmitted as a bradcast message and all participants in the network have to evaluate the UDP telegrams, which ties up considerable resources.

   What for a system is the destination for all transmissions? If you using OpenCPN you can connect the wind sensor with a second TCP connection. That is possible. You dont need to using the multiplexer for the wind sensor data.

   The source code is open and you are welcome to add a UDP transmission. You can find the current source code here:

   https://github.com/norbert-walter/Windsensor_Yachta

   Norbert

    dagnall ***@***.***> hat am 21.03.2024 12:35 CET geschrieben:

   I am trying to assist a user of your wifi Anemometer to connect into a boat network using a NMEA4WIFI multiplexer.He will connect to the Multiplexer AP, (and will also connect a PC/Tablet (+openCPN) to this AP.)
   It is not appropriate in this situation to use TCP for the anemometer<>multiplexer link, as the Multiplexer can only support a single TCP link, thus preventing the PC<>multiplexer from using TCP.
   A better approach is to use UDP (broadcast) from the anemometer, as this data can then be "seen" both by the multiplexer and also by the Tablet/Pc that is also connected to the Multiplexer AP.
   Open CPN has the facility to accept multiple "connections" and I have confirmed with practical simulations that an Anemometer could (eg) send nmea0183 on UDP port 8080, and the Multiplexer can send (eg AIS etc) on UDP port 2000.
   However, looking at the source code, I could not see any UDP transmission. Is this hidden? or missing?If Missing, is there a version of the software that offers UDP transmission options?
   —Reply to this email directly, view it on GitHub, or unsubscribe.You are receiving this because you are subscribed to this thread.Message ID: ***@***.***>

dagnall53, 2024-03-21:
Thanks.
My correspondent is French, so we may have had some (google) translate errors.
He has now advised that he is unable to connect to the NMEA4WIFI multiplexer Access Point, and I now think this may be due to differences in terminology (client / external network/  access point ).

He is trying to get the Anemometer to connect to the WIFI Access Point created by the NMEA4WIFI. (this is password protected).  A laptop, phone and other devices will also connect to the NMEA4WIFI Access point.

He can then multiplex the data from a number of NMEA0183 sources and make this available from the NMEA4WIFI. To make the data simultaneously available on (eg)  Navionics on phone and OpenCPN on PC, it is most suitable to use UDP.  TCP would only be available to one or device at a time.

Looking at your source I think you can allow the anemometer to connect to an existing external WIFI network, and you appear to call this a "WLAN CLIENT" in your setup?
My correspondent sent me a screen capture of the anemometer setup, which appears to show "WLAN CLIENT", where he can enter "NMEA4WIFI"  but no field to add password ?? .
Can you paste a photo of the settings needed to connect to an existing WIFI network with the ssid "NMEA4WIFI", AND password "12345678" ?  It would assist greatly!

This is the image he sent us.
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

norbert-walter, 2024-03-21:
Okay I understand. The wind sensor should be part of the WiFi network of NMEA4WIFI multiplexer and send data to the device. You can also do this with TCP and the NMEA4WiFI. If the multiplexer has the WiFi **SSID**: _NMEA4WIFI_ and the **password**: _12345678_, then you have to enter this connection data in teh wind sensor in **Device Settings** under **WLAN Client SSID**: _NMEA4WIFI_ and **WLAN Client Password**: _12345678_. Then press the **Save** button and reboot the wind sensor. The reboot can also be achieved by briefly switching off the power on the wind sensor. After the boot, the blue LED lights up. If it is off, then the wind sensor has logged into the WiFi of the multiplexer. You should then see an IP address under **WLAN Clinet IP**. With the mutiplexer you have to proceed as described here (TCP Port for Receiving).

https://www.vela-navega.com/nmea4wifi/docs/nmea4wifi_files/RxTCP.html

The IP address must be the IP address of the wind sensor. For the **port** you use _6666_. As soon as the multiplexer has connected to the wind sensor, the wind sensor sends data to the multiplexer. The blue LED flashes every time data is transferred. This is also how it works with a TCP transmission with the multiplexer. Please give me feedback if it worked.

dagnall53, 2024-03-21:
Many thanks,
I will pass this on, but I have simulated with an esp8266 this afternoon, and although I managed to get the WiFi 1000 to connect to the NMEA4 (which I helped write) ,
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
but I could not see TCP data recieved on NMEA4, and it was then not possible to connect to the 192.168.4.23 for your websettings. (although I was still able to connect to your AP and use 192.168.4.1 )
I presumed these settings would send (TCP) (port 6666) to the NMEA4WIFI, which is at 192.168.4.1 ?
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

dagnall53, 2024-03-21:
The trouble with TCP is that all the IP addresses need to be specified!!  I suspect you are sending to a different address to the NMEA4's 192.168.4.1 ?
;-) UDP broadcast is (generally!) so much simpler!!
;-)

norbert-walter, 2024-03-21:
The problem is both WiFi network use the same network addresses 192.168.4.X. It is a routing problem. We need to separate the networks with different network addresses. At the moment I can't change the network basis address. It is hard coded in the firmware and the same as by NMEA4WIFI.

As a quick solution I compile a special version for you with a different network address. I think then is it working.

norbert-walter, 2024-03-21:
Please use this firmware V1.19. I changed the network address from wind sensor to 192.168.5.1

Unzip the file an make a firmware update.
[firmware.bin.zip](https://github.com/norbert-walter/Windsensor_Yachta/files/14706703/firmware.bin.zip)

dagnall53, 2024-03-22:
Hi,
I got Update error: *ERROR[4]: Not Enough Space when trying via the WIFI*,
when trying to OTA via WIFI , but the NodeFlash software over serial worked
fine. (I had forgotten about that software!)
FYI, Luis, who has been following this thread, notes I missed that the
NMEA4 and your device are BOTH servers, and so the NMEA4 will not be able
to (see/) connect to the Anemometer. BUT that does not stop Open CPN from
seeing the anemometer!.
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
dagnall53, 2024-03-22:
Yes, it works!
Thanks,
I will also try the alternate approach .. and change our SSID AP range -
It's something I rarely do as it is quite complex via the web interface
(deliberately- to avoid users getting confused!) , but I am afraid that my
OCD now has the better of me and now I need to find if that would work as
well! .

Many thanks..
Dagnall

On Fri, 22 Mar 2024 at 10:59, Norbert Walter ***@***.***>
wrote:

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

norbert-walter, 2024-03-22:
I solved the problem with a new firmware version V1.20. I changed the IP address from 192.168.4.1 to 192.168.5.1 If you want you can use the new firmware.

norbert-walter, 2024-03-22:
I use not the lib from Rob Tillaat. I use the lib from Tom Denton. The lib is included in my repository.

norbert-walter, 2024-03-22:
Fix in version V1.20

dagnall53, 2024-03-22:
Cannot use gitpod.  I have enough trouble with github! (I suspect I am quite a bit older than you and its a case of "old dogs and new tricks"!) sorry. But thanks for making me aware of it.
Tom Denton AMS_5600 library ???
I thought I had read the main page.. and found these libraries but where is the AS5600.h ?
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
Gitlab version has less data - unless I missed something?

norbert-walter, 2024-03-22:
I don't support the Github project page. I changed the project to Github. I have more possibilities with Github to integrate several technologies more. You find the lib for the As5600 direct in the file repository. Please refer the includes in main.

https://github.com/norbert-walter/Windsensor_Yachta/tree/main/src

Gitpod is very easy to use. But you need a free Github account. You don't need any software components. All runs in the web browser. You see a complete software development environment in your browser similar to PlatformIO. Please try it! It is really easy and runs out of the box without any problems. Tip from a old dog to a old dog ;-)

dagnall53, 2024-03-23:
"_**I don't support the Github project page. I changed the project to Github. I have more possibilities with Github**_ "
I think perhaps auto correct got involved?? ;-)  one of those should have been gitLAB.. (?)
I have now copied the proper Github version.. so have the AS5600.h file..
The subtle difference in gitlab version I had copied was as5600 was a "proper library" so in <> ! It shows how hard it is to see these small differences!
I have had some feedback from the user, and I will see if I can send you an email as its not that relevant to this thread, which can now be closed!

norbert-walter, 2024-03-23:
That was exactly the reason for me to switch from the Arduino IDE to PlatformIO. The issue of integrating the right libs is not solved satisfactorily under the Arduino IDE and causes major problems when projects with many libs are used by others. The new version 2.0 of the Arduino IDE doesn't change much. See your own questions. With PlatformIO, the correct libs are always loaded in the correct version because you can specify them precisely. Since PlatformIO is integrated as a plugin in Visual Studio Code, you end up back at Microsoft and Github. I'm not a Microsoft fan, but for me Visual Studio Code is far better at programming than the Arduino IDE, especially if you want to implement extensive software projects. GitLab also works, but the integration into VSC is not as smooth as with Guthub. With Gitpod the whole thing becomes even easier because you don't even have to install VSC and PlatformIO. Everything runs out of the box in the web browser. Simple as it gets. This saves you a lot of work and frustration when installing a software development environment and runs on any device, including your cell phone or tablet. You can use it directly anywhere in the world. Just try it! Then you can tell me what you don't like about it.

dagnall53, 2024-03-23:
I sent an email, but will just close this with saying I need to explore  Visual Studio Code. I have used it for modifications for Marlin for the ender3.. but with great difficulty!
It just does not feel at all familiar to me.

Closed 2024-03-22.

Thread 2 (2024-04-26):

Update Error 1.15->1.20 "Magic Byte ist wrong, not 0xE9

Surfer2010, 2024-04-26:
Hallo Norbert,

beim Update von v1.15 auf 1.20 ist wiederholt folgende Fehlermeldung aufgetreten:
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

Wie können wir das lösen oder beheben/umgehen?
Danke

norbert-walter, 2024-08-10:
Wie würde das Update durchgeführt? Durch die Weboberfläche oder das Web Flashtool?

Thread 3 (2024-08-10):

Firmware update not working

EdKok, 2024-08-10:
Board is v2.0
Firmware is v1.18

Device shows 1.20 is available (via internet), button responds with that a message will show after succes but never happens.
Tried via local file from iPad and Android phone. File is seen but after button the browser looses connection after 10 seconds.
Is there anything I’m doing wrong?

norbert-walter, 2024-08-10:
Attention! The local IP address changed after Update to V1.20 from 192.168.4.1  to 192.168.5.1.

EdKok, 2024-08-11:
I saw that in the release notes but the update is just not happening. Think there is a reset/reboot after 10 seconds or so and happily connects back to SignalK, still running v1.8

norbert-walter, 2024-08-11:
Let me look in the software. I want to check the update function.Am 11.08.2024 10:45 schrieb EdKok ***@***.***>:
I saw that in the release notes but the update is just not happening. Think there is a reset/reboot after 10 seconds or so and happily connects back to SignalK, still running v1.8

—Reply to this email directly, view it on GitHub, or unsubscribe.You are receiving this because you commented.Message ID: ***@***.***>

EdKok, 2024-08-16:
While being closer to the device it did succeed now.

Closed 2024-08-16.

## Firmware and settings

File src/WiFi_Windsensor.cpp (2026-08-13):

//*********************************************************************************************
// WiFi and NMEA server for transmitting wind sensor data via TCP connection
// (C) Norbert Walter 2023
// License: GNU GPL V3
// https://www.gnu.org/licenses/gpl-3.0.txt
//
// WiFi_Windsensor.cpp
//
// Tested and compiled with Visual Studio Code and PlatformIO
// Board esp8266 V2.7.4 (2.2.2-dev(38a443e))
// The server use different NMEA centeces
//
// Wind direction and speed:  $WIMWV,x.x,a,x.x,a,A*hh
// Wind direction and speed:  $WIVWR,x.x,a,x.x,N,x.x,M,x.x,K*hh
// Down wind speed:           $WIVPW,x.x,N,x.x,M*hh                               (Wind speed parallel to wind direction)
// Wind speed informations:   $PWINF,0,x.x,D,x.x,D,x.x,M,x.x,K,x.x,N,x.x,B,A*hh   (Custom sentence)
// Wind sensor temperature:   $PWWST,C,0,x.x,A*hh                                 (Custom sentence)
//
//*********************************************************************************************

// Includes
#include <ESP8266WiFi.h>    // WiFi lib with TCP server and client

#include <WiFiClient.h>             // WiFi lib for clients
#include <ESP8266WebServer.h>       // WebServer lib
#include <ESP8266mDNS.h>            // DNS lib
#include <ESP8266HTTPUpdateServer.h>// Web Update server

#include <Ticker.h>         // Timer lib
#include <EEPROM.h>         // EEPROM lib
#include <WString.h>        // Needs for structures
#include <OneWire.h>        // 1Wire network lib
#include <Wire.h>           // Lib for I2C
#include <Adafruit_Sensor.h>// Adafuit sensor lib
#include <Adafruit_BME280.h>// Lib for BME280
#include "AS5600.h"         // Lib for magnetic rotation sensor AS5600
#include "MT6701_I2C.h"     // Lib for magnetic rotation sensor MT6701
#include <DallasTemperature.h>// Dallas 1Wire lib
#include <SimplyAtomic.h>   // This library includes the ATOMIC_BLOCK macro
#include "Configuration.h"  // Setup data structure in header file
#include "Definitions.h"    // Local definitions in additional file

AMS_5600 ams5600;           // Declare magnetic rotation sensor AS5600
MT6701I2C mt6701(&Wire);    // Declare magnetic rotation sensor MT6701
Adafruit_BME280 bme;        // Declare environment sensor BME280
OneWire oneWire(ONE_WIRE_BUS); // Declare 1Wire
DallasTemperature DS18B20(&oneWire); // Declare DS18B20
configData actconf;         // Actual configuration, Global variable
                            // Overload with old EEPROM configuration by start. It is necessarry for port and serspeed
                            // Don't change the position!

#include "Calculation.h"    // Function library for wind data calculation
#include "FunctionsLib.h"   // Function library
#include "NMEATelegrams.h"  // Function library for NMEA telegrams
#include "icon_html.h"      // Favorit icon
#include "css_html.h"       // CSS cascading style sheets
#include "steel_html.h"     // JavaScript steelseries_micro.js.gz library
#include "tween_html.h"     // JavaScript tween-min.js.gz library
#include "js_html.h"        // JavaScript functions
#include "main_html.h"      // Main webpage
#include "settings_html.h"  // Settings webpage
#include "firmware_html.h"  // Firmware update webpage
#include "add.h"            // Device self description as JSON for external AI models
#include "add_json.h"       // ADD JSON as native JSON 
#include "add_html.h"       // ADD JSON as webpage 
#include "json_html.h"      // JSON webpage
#include "json2_html.h"     // JSON webpage for Hall sensor signals
#include "MD5_html.h"       // JavaScript crypt password with MD5
#include "restart_html.h"   // Reset info webpage
#include "devinfo_html.h"   // Device info webpage
#include "windv_html.h"     // Wind value webpage
#include "windi_html.h"     // Wind instrument webpage
#include "error_html.h"     // Error 404 webpage

// Declarations
int value;                  // Value from first byte in EEPROM
int empty;                  // If EEPROM empty without configutation then set to 1 otherwise 0
configData defconf;         // Definition of default configuration data
configData oldconf;         // Configuration stucture for old config data in EEPROM
configData newconf;         // Configuration stucture for new config data in EEPROM

ESP8266WebServer httpServer(actconf.httpport);  // Port for HTTP server
ESP8266HTTPUpdateServer httpUpdater;            // Declaration update server
MDNSResponder mdns;                             // Activate DNS responder

Ticker Timer2;              // Declare Timer2 for average building
Ticker Timer3;              // Declare Timer3 for normal NMEA data sending
Ticker Timer4;              // Declare Timer4 for reduced NMEA data sending
Ticker Timer5;              // Declare Timer5 for calculation of windspeed und winddirection 
WiFiServer server(actconf.dataport);  // Declare WiFi NMEA server port
 
//*********************************************************************************************
// Setup section
//*********************************************************************************************
void setup() {
   // Start bus systems
   Wire.begin();                        // Start I2C
   bme.begin(i2cAddressBME280);         // Start BME280

   // !!!!!! Uncomment this line if you using a new configuration structure !!!!!!
//  saveEEPROMConfig(defconf);
  
  // Read the first byte from the EEPROM
  EEPROM.begin(sizeEEPROM);
  value = EEPROM.read(cfgStart);
  EEPROM.end(); 
  // If the fist Byte not identical to the first value in the default configuration then saving a default configuration in EEPROM.
  // Means if the EEPROM empty then saving a default configuration.
  if(value == defconf.valid){
    empty = 0;                  // Marker for configuration is present
  }
  else{
    saveEEPROMConfig(defconf);
    empty = 1;                  // Marker for configuration is missing
  }

  // Loading EEPROM configuration
  actconf = loadEEPROMConfig(); // Overload with old EEPROM configuration by start. It is necessarry for serspeed

  // If the firmware version in EEPROM different to defconf then save the new version in EEPROM
  if(String(actconf.fversion) != String(defconf.fversion)){
    String fver = defconf.fversion;
    fver.toCharArray(actconf.fversion, 6);
    saveEEPROMConfig(actconf);
  }
 
  // Pin definitions and settings for wind sensor types Yachta and Jukolein
  if(String(actconf.windSensorType) == "Jukolein"){
    
    // Pin redefinition for other wind sensor types (Original values see Definition.h)
    // Attention! GPIO 12 is not available! (1Wire)
    // Existing pins
    ledPin = 14;                // LED GPIO 14 (fake) (D5)
    INT_PIN1 = 2;               // Wind speed GPIO 2 (Hall sensor) (D4)
    INT_PIN2 = 16;              // Wind direction GPIO 16 (Hall sensor fake) (D0)
    // New pins
    I2C_SCL = 5;                // Wind direction magnetic sensor SCL GPIO 5 (AS5600) (D1)
    I2C_SDA = 4;                // Wind direction magnetic sensor SDA GPIO 4 (AS6500) (D2)
  }

  // Pin definitions and settings for wind sensor types Yachta
  if(String(actconf.windSensorType) == "Yachta"){
    
    // Pin redefinition for other wind sensor types (Original values see Definition.h)
    // Attention! GPIO 12 is not available! (1Wire)
    // Existing pins
    ledPin = 2;                 // LED GPIO 2 (D4)
    INT_PIN1 = 14;              // Wind speed GPIO 14 (Reed switch) (D5), pin need 10k and 100n for spike reduction
    INT_PIN2 = 16;              // Wind direction GPIO 16 (Hall sensor fake) (D0)
    // New pins
    I2C_SCL = 5;                // Wind direction magnetic sensor SCL GPIO 5 (AS5600) (D1)
    I2C_SDA = 4;                // Wind direction magnetic sensor SDA GPIO 4 (AS6500) (D2)
  }

  if(String(actconf.windSensorType) == "Yachta 2.0"){
    
    // Pin redefinition for other wind sensor types (Original values see Definition.h)
    // Attention! GPIO 12 is not available! (1Wire)
    // Existing pins
    ledPin = 2;                 // LED GPIO 2 (D4)
    INT_PIN1 = 14;              // Wind speed GPIO 14 (Reed switch) (D5), pin need 10k and 100n for spike reduction
    INT_PIN2 = 16;              // Wind direction GPIO 16 (Hall sensor fake) (D0)
    // New pins
    I2C_SCL = 5;                // Wind direction magnetic sensor SCL GPIO 5 (MT6701) (D1)
    I2C_SDA = 4;                // Wind direction magnetic sensor SDA GPIO 4 (MT6701) (D2)
    mt6701.begin(I2C_SDA, I2C_SCL);
  }

  // Pin definitions and settings for wind sensor types Ventus
  if(String(actconf.windSensorType) == "Ventus"){
    
    // Pin redefinition for other wind sensor types (Original values see Definition.h)
    // Attention! GPIO 12 is not available! (1Wire)
    // Existing pins
    ledPin = 2;                 // LED GPIO 2 (D4)
    INT_PIN1 = 14;              // Wind speed GPIO 14 (Reed switch) (D5), pin need 10k and 100n for spike reduction
    INT_PIN2 = 16;              // Wind direction GPIO 16 (Hall sensor fake) (D0)
    // New pins
    I2C_SCL = 5;                // Wind direction magnetic sensor SCL GPIO 5 (AS5600) (D1)
    I2C_SDA = 4;                // Wind direction magnetic sensor SDA GPIO 4 (AS6500) (D2)
  }
  
  // Pin settings
  pinMode(INT_PIN1, INPUT_PULLUP);  // Interrupt input 1 speed
  pinMode(INT_PIN2, INPUT_PULLUP);  // Interrupt input 2 direction
  pinMode(ledPin, OUTPUT);          // LED Pin output
  digitalWrite(ledPin, LOW);        // Switch LED on (inverted!)

  Serial.begin(actconf.serspeed);   // Start serial communication
  delay(10);

//  DebugPrint(3, "First EEPROM byte: ");
//  DebugPrintln(3, value);

  // ESP8266 Information Data
  DebugPrintln(3, "Booting Sketch...");
  DebugPrint(3, actconf.devname);
  DebugPrint(3, " ");
  DebugPrint(3, actconf.windSensorType);
  DebugPrint(3, " ");
  DebugPrint(3, actconf.fversion);
  DebugPrintln(3, " (C) Norbert Walter");
  DebugPrintln(3, "*********************************************");
  DebugPrintln(3, "");
  DebugPrintln(3, "Modul Type: ESP8266");
  DebugPrint(3, "SDK-Version: ");
  DebugPrintln(3, ESP.getSdkVersion());
  DebugPrint(3, "ESP8266 Chip-ID: ");
  DebugPrintln(3, ESP.getChipId());
  DebugPrint(3, "ESP8266 Speed [MHz]: ");  
  DebugPrintln(3, ESP.getCpuFreqMHz());
  DebugPrint(3, "Free Heap Size [Bytes]: ");
  DebugPrintln(3, ESP.getFreeHeap());
  DebugPrintln(3, "");
  DebugPrint(3, "Sensor ID: ");
  DebugPrintln(3, actconf.sensorID);
  DebugPrint(3, "Wind Sensor Type: ");
  DebugPrintln(3, actconf.windSensorType);
  DebugPrintln(3, "Sensor Type: Wind Speed");
  DebugPrint(3, "Input Pin: GPIO ");
  DebugPrintln(3, INT_PIN1);
  DebugPrintln(3, "Value Range [kn]: 0...73");
  DebugPrint(3, "Sensor Type: ");
  if(String(actconf.windType) == "R"){
      DebugPrintln(3, "Relative ");
    }
    else{
      DebugPrintln(3, "True ");
    }    
  if(String(actconf.windSensorType) == "WiFi 1000"){  
    DebugPrintln(3, "Wind direction");
    DebugPrint(3, "Input Pin: GPIO ");
    DebugPrintln(3, INT_PIN2);
    DebugPrintln(3, "Value Range [°]: 0...360");
  }
  if(String(actconf.windSensorType) == "Yachta" || String(actconf.windSensorType) == "Jukolein" || String(actconf.windSensorType) == "Ventus"){
    DebugPrintln(3, "Wind direction: AS5600");
    DebugPrint(3, "SCL: GPIO ");
    DebugPrintln(3, SCL);
    DebugPrint(3, "SDA: GPIO ");
    DebugPrintln(3, SDA);
    DebugPrint(3, "Scan I2C at address 0x");
    if (i2cAddressAS5600 < 0x10) {
      DebugPrint(3, "0");
    }
    DebugPrint(3, String(i2cAddressAS5600, HEX));
    DebugPrint(3, ": ");
    Wire.beginTransmission(i2cAddressAS5600);
    if(Wire.endTransmission() == 0){
      i2creadyAS5600 = 1;                        // Result I2C scan
      DebugPrintln(3, "ready");
      DebugPrint(3, "Magnitude [1]: ");
      DebugPrintln(3, ams5600.getMagnitude());
      DebugPrint(3, "Raw Angle [°]: ");
      magsensor = ams5600.getRawAngle() * 0.087; // 0...4096 which is 0.087 of a degree
      DebugPrintln(3, magsensor);
    }
    else{
      i2creadyAS5600 = 0;                        // Result I2C scan
      DebugPrintln(3, "error");
      DebugPrintln(3, "Stop I2C for device AS5600");
    }
  }

  if(String(actconf.windSensorType) == "Yachta 2.0"){
    DebugPrintln(3, "Wind direction: MT6701");
    DebugPrint(3, "SCL: GPIO ");
    DebugPrintln(3, SCL);
    DebugPrint(3, "SDA: GPIO ");
    DebugPrintln(3, SDA);
    DebugPrint(3, "Scan I2C at address 0x");
    if (i2cAddressMT6701 < 0x10) {
      DebugPrint(3, "0");
    }
    DebugPrint(3, String(i2cAddressMT6701, HEX));
    DebugPrint(3, ": ");
    Wire.beginTransmission(i2cAddressMT6701);
    if(Wire.endTransmission() == 0){
      i2creadyMT6701 = 1;                       // Result I2C scan
      DebugPrintln(3, "ready");
      DebugPrint(3, "Raw Value: ");
      mt6701.begin();
      DebugPrintln(3, mt6701.getRawAngle());
      DebugPrint(3, "Raw Angle [°]: ");
      magsensor = mt6701.getDegreesAngle();     // 0...16384 which is 0.0219 of a degree
      DebugPrintln(3, magsensor);
    }
    else{
      i2creadyMT6701 = 0;                       // Result I2C scan
      DebugPrintln(3, "error");
      DebugPrintln(3, "Stop I2C for device MT6701");
    }
  }

  if(String(actconf.windSensorType) == "Ventus"){
    DebugPrintln(3, "Environment Sensor: BME280");
    DebugPrint(3, "SCL: GPIO ");
    DebugPrintln(3, SCL);
    DebugPrint(3, "SDA: GPIO ");
    DebugPrintln(3, SDA);
    DebugPrint(3, "Scan I2C at address 0x");
    if (i2cAddressBME280 < 0x10) {
      DebugPrint(3, "0");
    }
    DebugPrint(3, String(i2cAddressBME280, HEX));
    DebugPrint(3, ": ");
    Wire.beginTransmission(i2cAddressBME280);
    if(Wire.endTransmission() == 0){
      i2creadyBME280 = 1;                        // Result I2C scan
      DebugPrintln(3, "ready");
      DebugPrint(3, "Temperature [°C]: ");
      airtemperature = bme.readTemperature();
      DebugPrintln(3, airtemperature);      
      DebugPrint(3, "Air Pressure [mbar]: ");
      airpressure = bme.readPressure() / 100;
      DebugPrintln(3, airpressure);
      DebugPrint(3, "Air Humidity [%]: ");
      airhumidity = bme.readHumidity();
      DebugPrintln(3, airhumidity);
      DebugPrint(3, "Altitude [m]: ");
      altitude = bme.readAltitude(SEALEVELPRESSURE_HPA);
      DebugPrintln(3, altitude);
    }
    else{
      i2creadyBME280 = 0;                        // Result I2C scan
      DebugPrintln(3, "error");
      DebugPrintln(3, "Stop I2C for device BME280");
    }
  }
    
  DebugPrintln(3, "Sensor Type: Sensor Temp 1Wire");
  DebugPrint(3, "Input Pin: GPIO ");
  DebugPrintln(3, ONE_WIRE_BUS);
  DebugPrintln(3, "Value Range [°C]: -55...125");
  DebugPrint(3, "Send Period [ms]: ");
  DebugPrintln(3, SendPeriod);
  DebugPrint(3, "Reduced Send Period [ms]: ");
  DebugPrintln(3, RedSendPeriod);
  DebugPrintln(3, "");

  // Debug info for initialize the EEPROM
  if(empty == 1){
    DebugPrintln(3, "EEPROM config missing, initialization done");
  }
  else{
    DebugPrintln(3, "EEPROM config present");
  }

  // Loading EEPROM config
  DebugPrintln(3, "Loading actual EEPROM config");
  actconf = loadEEPROMConfig();
  DebugPrintln(3, "");

  // Starting access point for update server
  DebugPrint(3, "Access point started with SSID ");
  DebugPrintln(3, actconf.sssid);
  DebugPrint(3, "Access point channel: ");
  DebugPrintln(3, WiFi.channel());
//  DebugPrintln(3, actconf.apchannel);
  DebugPrint(3, "Max AP connections: ");
  DebugPrintln(3, actconf.maxconnections);
  WiFi.mode(WIFI_AP_STA);
  IPAddress local_IP(192,168,5,1);
  IPAddress gateway(192,168,5,255);
  IPAddress subnet(255,255,255,0);
  WiFi.softAPConfig(local_IP, gateway, subnet);
  WiFi.softAP(actconf.sssid, actconf.spassword, actconf.apchannel, false, actconf.maxconnections);
  hname = String(actconf.hostname) + "-" + String(actconf.sensorID);
  WiFi.hostname(hname);   // Provide the hostname
  DebugPrint(3, "Host name: ");
  DebugPrintln(3, hname);
  if(actconf.mDNS == 1){
    MDNS.begin(hname);      // Start mDNS service
    MDNS.addService("http", "tcp", actconf.httpport);       // HTTP service
    MDNS.addService("nmea-0183", "tcp", actconf.dataport);  // NMEA0183 data service for AVnav
  }  
  DebugPrintln(3, "mDNS service: activ");
  DebugPrint(3, "mDNS name: ");
  DebugPrint(3, hname);
  DebugPrintln(3, ".local");
  
  // Sart update server
  httpUpdater.setup(&httpServer);
  httpServer.begin();
  DebugPrint(3, "HTTP Update Server started at port: ");
  DebugPrintln(3, actconf.httpport);
  DebugPrint(3, "Use this URL: ");
  DebugPrint(3, "http://");
  DebugPrint(3, WiFi.softAPIP());
  DebugPrintln(3, "/update");
  DebugPrintln(3, "");

  #include "ServerPages.h"    // Webserver pages request functions
  
  // Connect to WiFi network
  DebugPrint(3, "Connecting WiFi client to ");
  DebugPrintln(3, actconf.cssid);

  // Load connection timeout from configuration (maxccount = (timeout[s] * 1000) / 500[ms])
  maxccounter = (actconf.timeout * 1000) / 500;
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
void loop() {
  
  httpServer.handleClient();        // HTTP Server-handler for HTTP update server
  MDNS.update();                    // Update DNS info
  
  // Check if a client is connected
  WiFiClient client = server.available();
  int i = 0;
  
  if(!client.connected() && WiFi.status() != WL_CONNECTED){
    digitalWrite(ledPin, LOW);      // LED on (Low activ)
    i = 0;
  }

  // While client is connected or Serial Mode is active
  while (client.connected() && !client.available()) {
    digitalWrite(ledPin, HIGH);     // LED off (Low activ)
    
    httpServer.handleClient();      // HTTP Server-handler for HTTP update server
    if(actconf.mDNS == 1){
      MDNS.update();                // Update DNS info  
    }  
    
    if ((i == 0) && ((int(actconf.serverMode) == 0) || (int(actconf.serverMode) == 4))) {
      DebugPrintln(3, "Client connected");
      DebugPrintln(3, "");
    }

    // Wind speed and wind direction data calculated via Timer5 interrupt all 500ms

    // Sending NMEA data with normal speed
    if (windspeed_mps > 0 && flag1 == true){     
      i++;
      DebugPrintln(3, "");
      DebugPrint(3, "Send package:");
      DebugPrintln(3, i);
          
      if((int(actconf.serverMode) == 0) || (int(actconf.serverMode) == 1) || (int(actconf.serverMode) == 4)){
         if(int(actconf.windSensor) == 1){
          client.println(sendMWV(1));  // Send NMEA telegrams
          client.println(sendVWR(1));
          client.println(sendVPW(1));
          client.println(sendINF(1));
         }
        if(int(actconf.tempSensor) == 1){
          if(String(actconf.tempSensorType) == "DS18B20"){
            client.println(sendWST(1));
          }
          if(String(actconf.tempSensorType) == "BME280"){
            client.println(sendWSE(1));
          }    
        } 
      }
         
      flashLED(10);                 // Flash LED for data transmission
      flag1 = false;                // Reset the flag
    }

    // Sending NMEA data with reduced speed
    if (windspeed_mps <= 0 && flag2 == true){
      i++;
      DebugPrintln(3, "");
      DebugPrint(3, "Send package:");
      DebugPrintln(3, i);
      
      if((int(actconf.serverMode) == 0) || (int(actconf.serverMode) == 1) || (int(actconf.serverMode) == 4)){
        if(int(actconf.windSensor) == 1){
          client.println(sendMWV(1));  // Send NMEA telegrams
          client.println(sendVWR(1));
          client.println(sendVPW(1));
          client.println(sendINF(1));
        }
        if(int(actconf.tempSensor) == 1){
          if(String(actconf.tempSensorType) == "DS18B20"){
            client.println(sendWST(1));
          }
          if(String(actconf.tempSensorType) == "BME280"){
            client.println(sendWSE(1));
          }    
        }
      }
           
      flashLED(10);                 // Flash LED for data transmission
      flag2 = false;                // Reset the flag
    }

  }

  // If client not connected and server mode 1 (NMEA Serial) or server mode 4 (Demo)
  if(!client.connected() && (int(actconf.serverMode) == 1 || int(actconf.serverMode) == 4)){
    // Sending NMEA data with normal speed
    if (windspeed_mps > 0 && flag1 == true){  
      if(int(actconf.windSensor) == 1){
        sendMWV(1);  // Send NMEA telegrams
        sendVWR(1);
        sendVPW(1);
        sendINF(1);
      }
      if(int(actconf.tempSensor) == 1){
        if(String(actconf.tempSensorType) == "DS18B20"){
          sendWST(1);
        }
        if(String(actconf.tempSensorType) == "BME280"){
          sendWSE(1);
        }    
      }

      flashLED(10);                 // Flash LED for data transmission
      flag1 = false;                // Reset the flag
    }

    // Sending NMEA data with reduced speed
    if (windspeed_mps <= 0 && flag2 == true){      
      if(int(actconf.windSensor) == 1){
        sendMWV(1);  // Send NMEA telegrams
        sendVWR(1);
        sendVPW(1);
        sendINF(1);
      }
      if(int(actconf.tempSensor) == 1){
        if(String(actconf.tempSensorType) == "DS18B20"){
          sendWST(1);
        }
        if(String(actconf.tempSensorType) == "BME280"){
          sendWSE(1);
        }    
      }
           
      flashLED(10);                 // Flash LED for data transmission
      flag2 = false;                // Reset the flag
    }
  }

  delay(150);                       // Delay for load reducing
}

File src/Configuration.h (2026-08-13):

#ifndef Configuration_h
#define Configuration_h

// Default configuration
// Types 'byte' und 'word' doesn't work!
typedef struct {
  int valid = 11;                           // Number of configuration (Please change when the structure or values are changed)
  int crypt = 0;                            // Activate for critical webside a password query [0 = off|1 = on]
  char password[31] = "12345678";           // Password for critical websides (settings, update and reboot)
  char devname[21] = "Windsensor";          // Device name for web configuration
  char crights[14] = "NoWa (C) 2026";       // Copy rights
  char fversion[6] = "V1.21";               // Firmware version
  char license[12] = "GNU GPL V3";          // License type
  int debug = 3;                            // Debug mode 0=off 1=Errors 2=Errors + Warnings 3=Errors + Warnings + Messages
  char cssid[31] = "MyBoat";                // SSID of WiFi Client
  char cpassword[31] = "S6587rr94P";        // Password of WiFi Client
  int timeout = 30;                         // Connection timeout for client in [s] [30|90|120|150|180|210|240|270|300]
  char sssid[31] = "Yachta";                // SSID of WiFi Server
  char spassword[31] = "12345678";          // Password of WiFi Server
  int apchannel = 1;                        // Assess Point channel [1...13]
  int maxconnections = 2;                   // Max number of connection for WiFi clients [1...4]
  int mDNS = 1;                             // Using mDNS service [0|1] 0=off, 1=on
  char hostname [31] = "windsensor";        // Hostname WiFi Server
  int dataport = 6666;                      // Port for NMEA data output
  int httpport = 80;                        // Port for HTTP and update pages
  int serverMode = 0;                       // Used server mode [0|1|2|3|4] 0=HTTP (JSON, NMEA), 1=NMEA Serial, 2=MQTT, 3=Diagnostic, 4=Demo (Simulation data)
  int serspeed = 115200;                    // Serial speed in [Bd] 8N1 [300|1200|2400|4800|9600|19200|38400|57600|74880|115200]
  int skin = 0;                             // Skin for websides [0|1|2]
  char instrumentType[8] = "complex";       // Instrument type [simple|complex] simple = Canvas HTML5 , complex = Canvas Steel Series library
  int instrumentSize = 400;                 // Instrument size X * Y [pix] [200|250|300|350|400|450|500|550|600]
  int sensorID = 0;                         // ID of sensor [0...9]
  char windSensorType[15] = "Yachta 2.0";   // Type of wind sensor [WiFi 1000|Yachta|Yachta 2.0|Jukolein|Ventus]
  int windSensor = 1;                       // Send wind data 0=off 1=on (WIMWV, WIVWR, WIVPW, PWINF) or Serial or JSON
  char windType[2] = "R";                   // Type of wind R=relative, T=true
  int offset = 0;                           // Offset of wind direction [-180°...+180°]
  int average = 1;                          // Number of values for average building [1...10], for high speed use 1, default use 2
  char speedUnit[5] = "kn";                 // Unit of speed [m/s|km/h|kn|bft] for WIMWV
  int downWindSensor = 1;                   // Send data to down wind 0=off 1=on (WIVPW)
  int downWindRange = 50;                   // Down wind area = 180° +/- downWindRange
  float calslope = 1.0;                     // Speed sensor calibration slope, default 1.0
  float caloffset = 0.0;                    // Speed sensor calibration offset, default 0.0
  char tempSensorType[10] = "DS18B20";      // Type of temperature sensor [Off|DS18B20|BME280]
  int tempSensor = 1;                       // Send data for temp 0=off 1=on (PWWST)
  char tempUnit[2] = "C";                   // Unit of temperature [C|F]
} configData;

#endif

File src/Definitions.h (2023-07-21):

#ifndef Definitions_h
#define Definitions_h           

// Passwort settings
String transactionID = String(random(0, 99999999));// Generate a random transaction ID by initialisation
String raw = "";                  // Uncrypted raw data
String crypt = "";                // Crypted data

// EEPROM settings (max size is 4096 Byte)
int cfgStart = 1024;              // Start adress in EEPROM (Attention! The first 32 Byte are used beginning with adress 0)
int sizeEEPROM = 2048;            // Used size of EEPROM 2kB (limit for config file size)

// WLAN client settings
String hname;                     // Hostname
int maxccounter;                  // Maximum number for connection tests until aborted (maxcounter = 60; 60 * 500ms = 30s waiting time)
int ccounter;                     // Actual connection test counter

// Settings for NMEA server 
int SendPeriod = 1000;            // SendPeriod in [ms], Attention! Range is limited [500...2000]
int RedSendPeriod = 3000;         // Reduced send period [ms] when wind speed is zero, range [2000...10000]
volatile bool flag1 = false;      // Flag for data sending (normal speed)
volatile bool flag2 = false;      // Flag for data sending (reduced speed)
volatile bool flag3 = false;      // Flag for zero wind speed detection (true = zero)

// Pin definitions WiFi 1000 wind sensor (default)
int ledPin = 2;                   // LED low activ GPIO 2 (D4)
int INT_PIN1 = 5;                 // Wind speed GPIO 5 (Hall sensor) (D1)
int INT_PIN2 = 4;                 // Wind direction GPIO 4 (Hall sensor) (D2)
int ONE_WIRE_BUS = 12;            // 1Wire bus on GPIO 12 (D6)

// I2C definitions
int I2C_SCL = 5;                  // I2C SCL
int I2C_SDA = 4;                  // I2C SDA
int i2creadyAS5600 = 0;           // Result of I2C scan for AS5600
byte i2cAddressAS5600 = 0x36;     // I2C address AS5600
int i2creadyMT6701 = 0;           // Result of I2C scan for MT6701
byte i2cAddressMT6701 = 0x06;     // I2C address MT6701
int i2creadyBME280 = 0;           // Result of I2C scan for BME280
byte i2cAddressBME280 = 0x76;     // I2C address BME280
#define SEALEVELPRESSURE_HPA (1013.25)// Sea level air pressure


// Measuring data (used in interrupt)
volatile int marker1 = 0;         // Wind speed
volatile int marker2 = 0;         // Wind direction
volatile int marker3 = 0;         // Marker for data saving in a array (sensor 1 and 2 binary switching data)
volatile int scounter = 0;        // Array counter for data saving (sensor1 and 2)
volatile int rpcounter = 0;       // Raw pulse counter for wind direction sensor (per revolution)
volatile int pcounter = 0;        // Pulse counter for wind direction sensor (per revolution)
volatile unsigned long icounter = 0;    // Interrupt counter for rotation detection
volatile unsigned long icounterold = 0; // Old interrupt counter for rotation detektion
volatile unsigned long counter1;  // Wind spped
volatile unsigned long counter2;  // Wind direction
volatile float time1;             // Wind speed (time in [ms] for one rotation)
volatile float time2;             // Wind direction (time in [ms] between wind speed sensor and wind direction sensor)
volatile int average;             // Number of values for average calculation [1...10]
volatile float timearray1[10];    // Array1 of time values (average building)
volatile float timearray2[10];    // Array2 of time values (average building)
volatile int mc = 0;              // Modulo counter
volatile float time1_avg;         // Average wind speed (time in [ms] for one rotation)
volatile float time2_avg;         // Average direction (time in [ms] between wind speed sensor and wind direction sensor)

static float radius = 0.06;       // Radius between center and middle of half hemisphere position (WiFi 1000)
static float radius2 = 0.043;     // Radius between center and middle of half hemisphere position (Yachta|Jukolein)
static float radius3 = 0.055;     // Radius between center and middle of half hemisphere position (Ventus)
static float lamda = 0.3;         // Lambda is a constant for amemometer type with 3 hemisphere, lamda = 0,3
static float pi = 3.14159265358979;   // Pi constant
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

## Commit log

2023-07-24 Add temperature compensation for DS18B20
2024-03-18 New version V1.19
    [Configuration.h]
2024-03-22 New firmware V1.20
    [Configuration.h]
2026-04-21 Add device descriptions
    [Configuration.h]
2026-04-24 Add new device description
2026-08-13 Change back to old status for number of configuration
    [Configuration.h]
